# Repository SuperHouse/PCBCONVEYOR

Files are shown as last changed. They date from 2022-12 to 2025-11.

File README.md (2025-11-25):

PCB Conveyor Belt
=================

Copyright 2021 SuperHouse Automation Pty Ltd  www.superhouse.tv

THIS IS VERY PRELIMINARY! I'm adding this work-in-progress to GitHub
so that Seon can access it, but it's not in a ready state for
general consumption.
^^^^^^^^^^^^^^^^^^^^^^^^^^^^^^^^^^^^^^^^^^^^^^^^^^^^^^^^^^^^^^^

A conveyor belt for linking together PCB assembly machines, including
pick-and-place, reflow, optical inspection, etc.

The width of the belt is adjustable to suit different sizes of PCBs
and panels. This project includes the design for the mechanical
structure, a controller, and firmware for the controller.

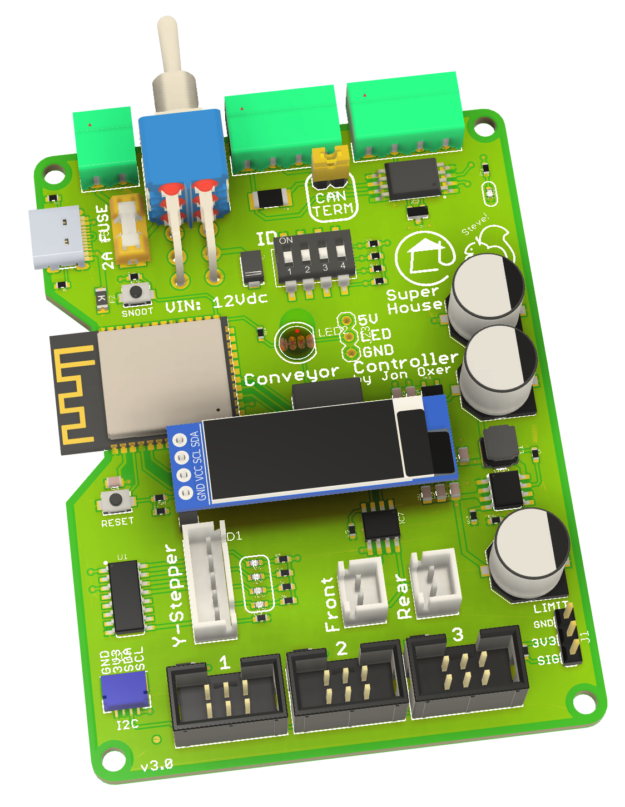
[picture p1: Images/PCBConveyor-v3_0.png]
PCBConveyor controller v3.0 PCB Controller


More information:

  http://www.superhouse.tv/pcbconveyor

INSTALLATION
------------
The "Hardware" directory contains the PCB design as an EAGLE project.
This can be imported into KiCAD, or opened natively using Fusion360.

CREDITS
-------
Designed by Jonathan Oxer jon@oxer.com.au

DISTRIBUTION
------------
The specific terms of distribution of this project are governed by the
license referenced below.

LICENSE
-------
Licensed under the TAPR Open Hardware License (www.tapr.org/OHL).
The "license" folder within this repository also contains a copy of
this license in plain text format.

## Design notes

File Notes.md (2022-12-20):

Design Notes
============

## Features

 * Speed control. Perhaps H-bridge motor drivers to allow reversing.
 * Width control. Needs a stepper driver. External module?
 * Ready-in / Ready-out connections.
 * Sensors at both ends to detect incoming / outgoing boards.
 * Ethernet to receive configuration commands.
 * Numeric keypad to set width / speed.
 * Display to show width setting.
 * Homing switch.
 * Calibration of homing switch offset.
 * Configure width using gcode commands.
 * Maybe configure speed using gcode too? Like spindle speed / direction.

I/O: Use MCP23017, and expose the extra pins on a spare header?

## General notes

Example conveyor:

https://www.alibaba.com/product-detail/KAYO-300-Automatic-PCB-Output-Connected_62495647850.html

Specs say that is 600-2200mm/min.

N20 motor 100RPM:

 * 12V = 3620mm/min
 * 4V = 1130mm/min
 * 3V = 780mm/min
 
Height from floor: SMEMA spec says 37" to 38" (940mm to 965mm)

## Software
The controller can be combined as a single device that provides the UI and also controls
the hardware, using custom firmware, OR it can be split so there's an I/O controller as
part of the chassis and a separate UI device.

The second approach as the advantage that the I/O controller can run GRBL:

 * Only enable the Y axis.
 * Use the spindle output to control the conveyor motor:
   * Spindle PWM speed control.
   * Spindle direction control.

With a separate I/O controller, it could be controlled by plugging in a USB cable from
a laptop and not having a UI controller at all.

https://github.com/gnea/grbl

However, how would it do ready-in/ready-out, and board detection? Custom firmware may
be better for those things.

### User Interface
https://www.bitsanddroids.com/creating-our-first-esp32-flight-display-graphics/

## Lighting
Should there be LED strips along the inside faces of the conveyor arms?

## Connections for controller

 * Ethernet
 * USB
 * 12V (PoE option)
 * Ready-in
 * Ready-out
 * Motor 1 out
 * Motor 2 out
 * Left-side sensor
 * Right-side sensor

## Controller
http://www.wireless-tag.com/portfolio/wt32-sc01/

### LCD driver
https://github.com/moononournation/Arduino_GFX

https://github.com/moononournation/Arduino_GFX/wiki/Dev-Device-Declaration

#include <Arduino_GFX_Library.h>
#define TFT_BL 23
Arduino_DataBus *bus = new Arduino_ESP32SPI(21 /* DC */, 15 /* CS */, 14 /* SCK */, 13 /* MOSI */, -1 /* MISO */);
Arduino_GFX *gfx = new Arduino_ST7796(bus, 22 /* RST */, 3 /* rotation */);

https://haswitchplate.github.io/openHASP-docs/0.6/devices/wt32-sc01/

https://www.alibaba.com/product-detail/WT32-SC01-ESP32-Dev-kitC-with_1600120762835.html

### Touch screen driver

https://stackoverflow.com/questions/58472138/find-ft6336-touch-screen-library-for-esp32

https://github.com/crystalfontz/CFAF240400C0-030SC/blob/master/CFAF240400C0030T/CFAF240400C0030SC.ino

https://github.com/strange-v/FT6X36

## Upstream / downstream connections

Needs a way to read from the adjacent device, and also to signal to
that device.

Open-collector input, with GND connection, a pullup, and a data in.

Dry-contact output. Perhaps a reed relay?

## Movement logic

### Incoming board

When there is no board ready to be sent, upstreams RO will not be
asserted.

When we're not ready for a board, our RI will not be asserted.

When upstream is ready to send a board, its RO will be asserted.

When we're ready to receive a board, our RI will be asserted.

When both RO and RI on upstream are asserted, start the belt.

## Board sensor

Sensor type: VL53L0X

VDD  Regulated 2.8 V output. Almost 150 mA is available to power
  external components. (If you want to bypass the internal regulator,
  you can instead use this pin as a 2.8 V input with VIN disconnected.)
 
VIN  This is the main 2.6 V to 5.5 V power supply connection. The SCL
  and SDA level shifters pull the I2C lines high to this level.
 
GND  The ground (0 V) connection for your power supply. Your I2C
  control source must also share a common ground with this board.
 
SDA  Level-shifted I2C data line: HIGH is VIN, LOW is 0 V
 
SCL  Level-shifted I2C clock line: HIGH is VIN, LOW is 0 V
 
XSHUT  This pin is an active-low shutdown input; the board pulls it up
  to VDD to enable the sensor by default. Driving this pin low puts
  the sensor into hardware standby. This input is not level-shifted. 

I2C address is 0x29 and can't be changed in hardware. The driver can
change it on startup. Use XSHUT to hold all others in shutdown while
that's being done.

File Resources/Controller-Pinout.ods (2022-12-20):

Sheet: Requirements
Count | Signal | Dir | Pin | Notes
1 | COPI | O | IO23
2 | CIPO | I | IO19
3 | SCK | O | IO18
4 | RFM69 CS | O | IO5
5 | SCL | O | IO22
6 | SDA | O | IO21
7 | RFM69 DIO0 | O | IO27
8 | Piezo | O | IO26
9 | Buttons | I | IO35 | Resistor Ladder
10 | Drive Motor PWM | O | IO16 | PWM
11 | Motor Relay A | O | IO17
12 | Motor Relay B | O | IO4
13 | Actuator Direction | O | IO25
14 | Encoder A | I | IO36
15 | Encoder B | I | IO39
16 | Limit Switches | I | IO34 | Resistor Ladder

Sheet: ESP32 Pinout
Pin | Input | Output | Notes | Touch | ADC | PWM | DAC | UART | SPI | I2C | Strap | HAB | Use
GPIO0 | Pulled up | OK | Outputs PWM signal at boot | T1 | ADC2_CH1 |  |  |  |  |  | Y |  | Boot Mode
GPIO2 | OK | OK | Connected to onboard LED | T2 | ADC2_CH2 | Y |  |  |  |  | Y |  | IN1
GPIO4 | OK | OK |  | T0 | ADC2_CH0 | Y |  |  |  |  | Y |  | IN2
GPIO5 | OK | OK | Outputs PWM signal at boot |  |  | Y |  |  | SS |  | Y | Y | IN3
GPIO12 | OK | OK | Boot fail if pulled high | T5 | ADC2_CH5 | Y |  |  |  |  | Y |  | IN4
GPIO13 | OK | OK |  | T4 | ADC2_CH4 | Y |  |  |  |  |  |  | LCD SDA
GPIO14 | OK | OK | Outputs PWM signal at boot | T6 | ADC2_CH6 | Y |  |  |  |  |  | Y | LCD SCL
GPIO15 | OK | OK | Outputs PWM signal at boot | T3 | ADC2_CH3 | Y |  |  |  |  | Y | Y | LCD CS
GPIO18 | OK | OK |  |  |  | Y |  |  | SCK |  |  |  | I2C SDA
GPIO19 | OK | OK |  |  |  | Y |  | CTS | CIPO |  |  |  | I2C SCL
GPIO21 | OK | OK |  |  |  | Y |  |  |  | SDA |  |  | LCD RS
GPIO22 | OK | OK |  |  |  | Y |  | RTS |  | SCL |  |  | LCD RST
GPIO23 | OK | OK |  |  |  | Y |  |  | COPI |  |  |  | LCD LED
GPIO25 | OK | OK |  |  | ADC2_CH8 | Y | DAC1 |  |  |  |  |  | MOTOR_1
GPIO26 | OK | OK |  |  | ADC2_CH9 | Y | DAC2 |  |  |  |  |  | MOTOR_2
GPIO27 | OK | OK |  | T7 | ADC2_CH7 | Y |  |  |  |  |  |  | ok
GPIO32 | OK | OK | Modify WROVER to use as output | T9 | ADC1_CH4 | Y |  |  |  |  |  |  | ok | https://www.esp32.com/viewtopic.php?t=2803
GPIO33 | OK | OK | Modify WROVER to use as output | T8 | ADC1_CH5 | Y |  |  |  |  |  |  | ok | https://www.esp32.com/viewtopic.php?t=2803
GPIO34 | OK | x | Input only. No pullup / pulldown. |  | ADC1_CH6 |  |  |  |  |  |  |  | ok
GPIO36 | OK | x | Input only. No pullup / pulldown. |  | ADC1_CH0 |  |  |  |  |  |  |  | ok | SENS_VP
GPIO39 | OK | x | Input only. No pullup / pulldown. |  | ADC1_CH3 |  |  |  |  |  |  |  | Limit sensor input | SENS_VN
 |  |  |  |  | ADC2 doesn't work when WiFi is in use

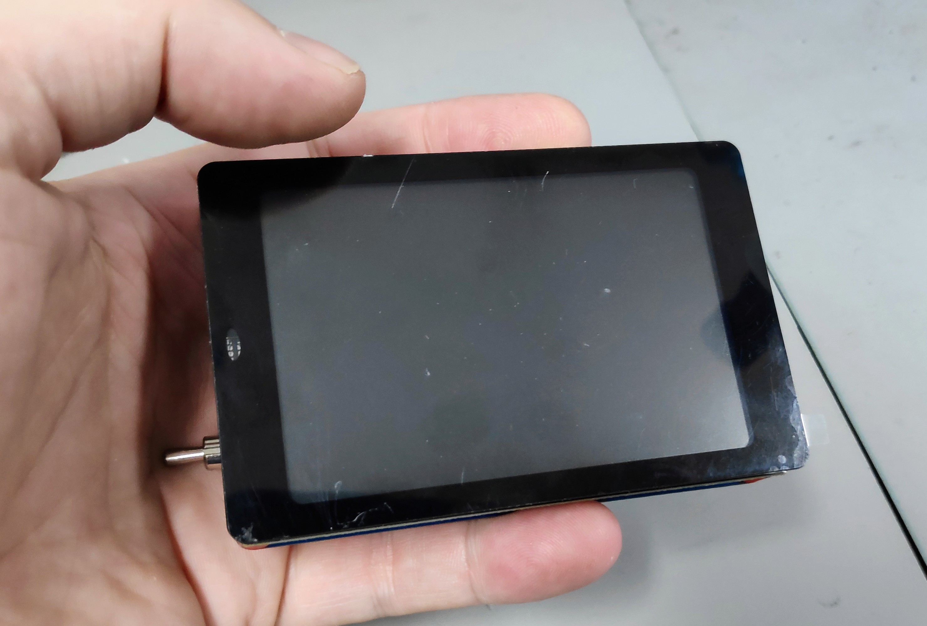
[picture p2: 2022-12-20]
Images/2022-03-01 10.30.43.jpg

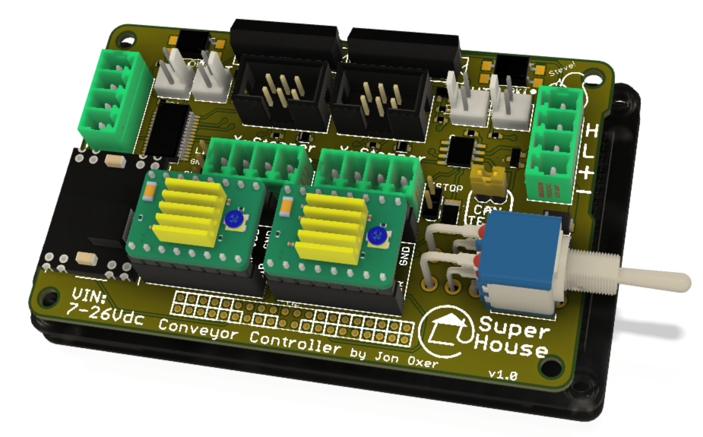
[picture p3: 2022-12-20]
Images/Screen Shot 2022-02-26 at 9.11.51 pm.png

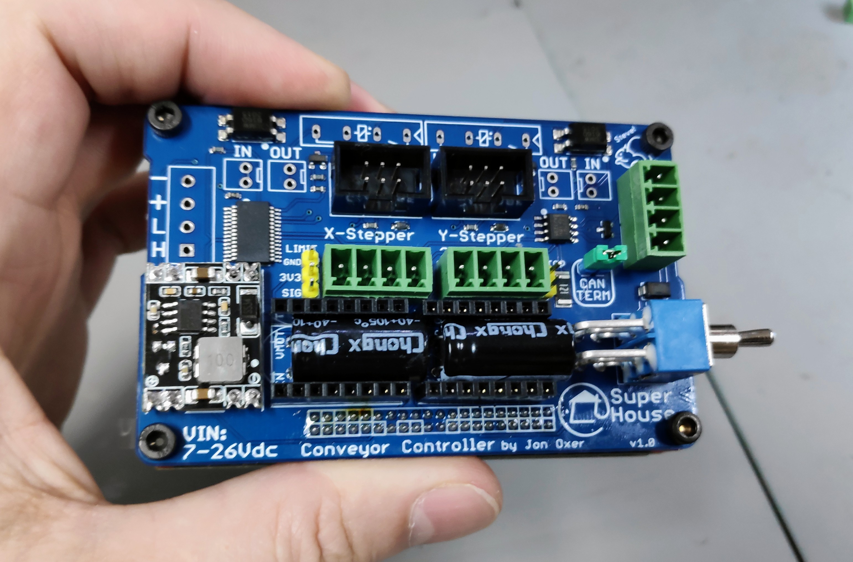
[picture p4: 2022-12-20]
Images/2022-03-01 10.30.50.jpg

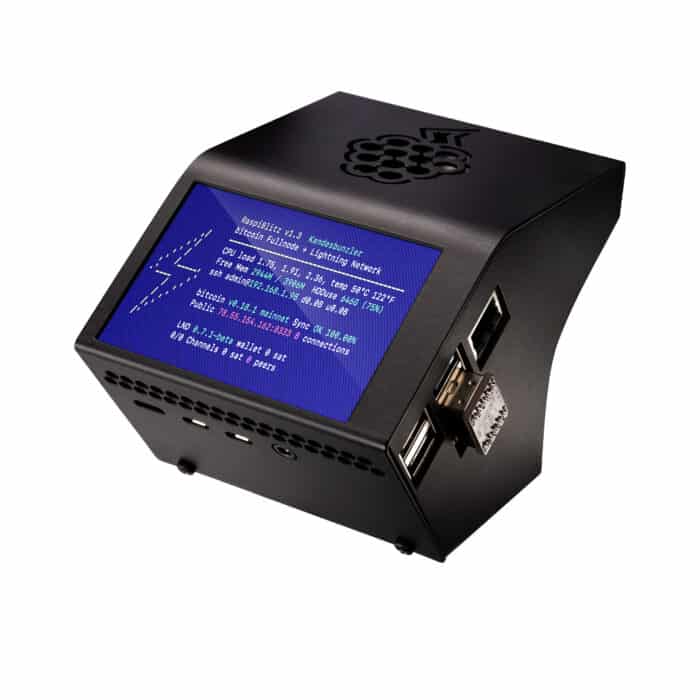
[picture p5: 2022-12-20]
Images/RaspiBlitz-Case.jpeg

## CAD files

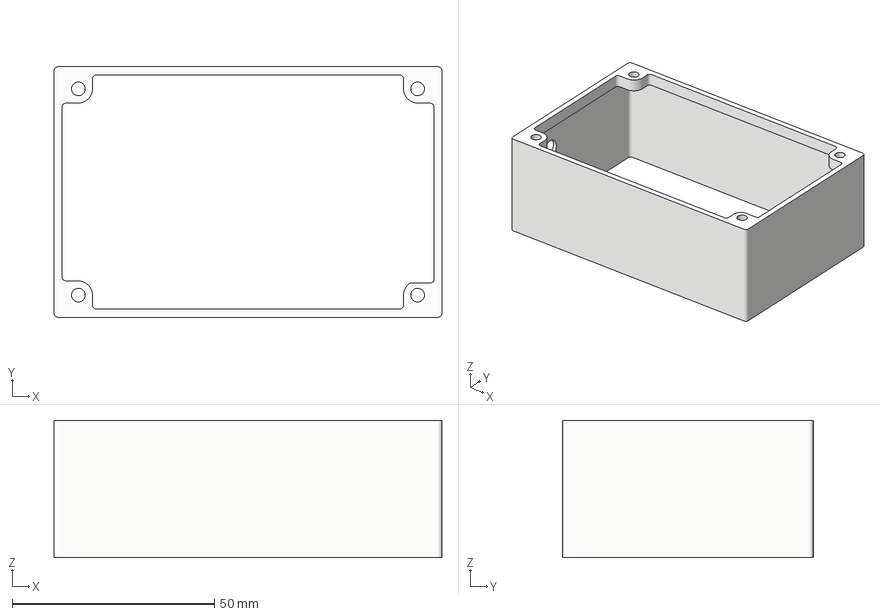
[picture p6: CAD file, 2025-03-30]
Mechanical/Conveyor Controller Mount.3mf
96.0 x 62.0 x 34.0 mm

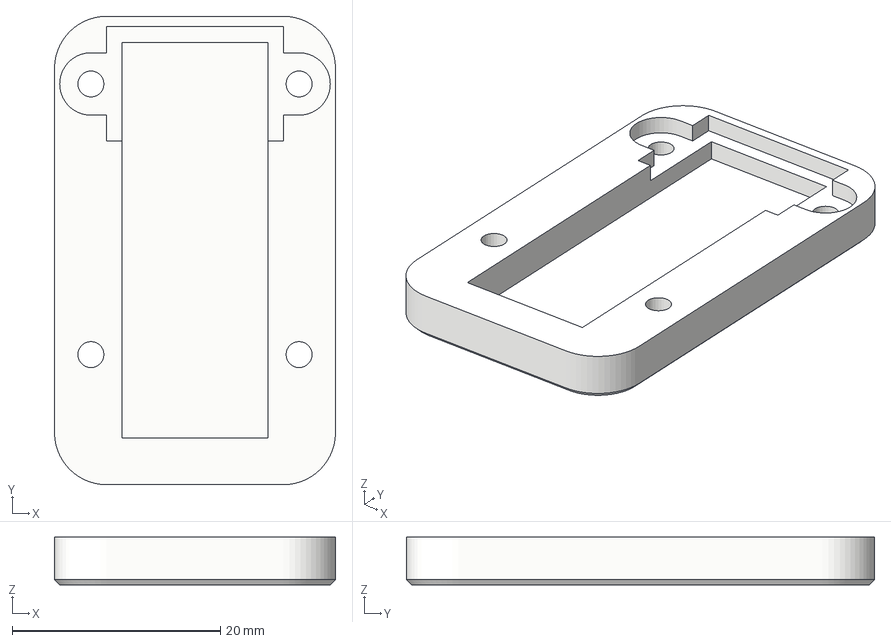
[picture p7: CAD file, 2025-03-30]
Mechanical/PCB Sensor Housing Base.3mf
27.0 x 45.0 x 4.60 mm

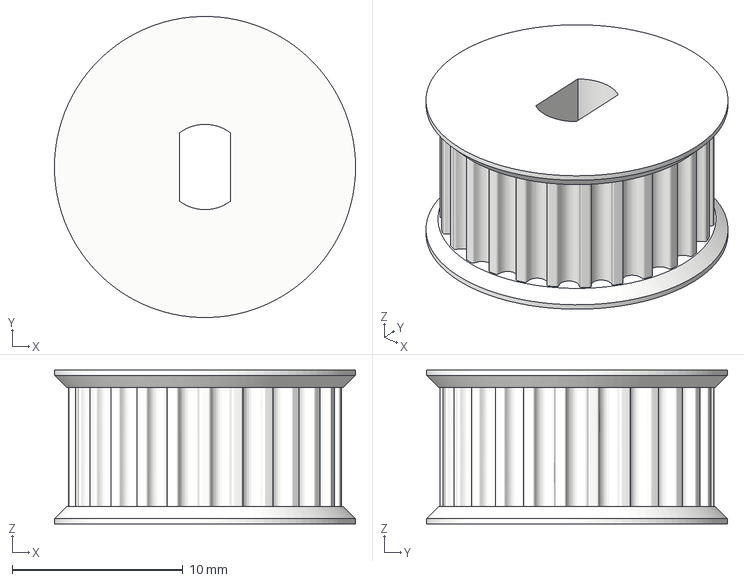
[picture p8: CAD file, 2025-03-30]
Mechanical/Belt Pulley GT2.3mf
17.6 x 17.6 x 9.00 mm

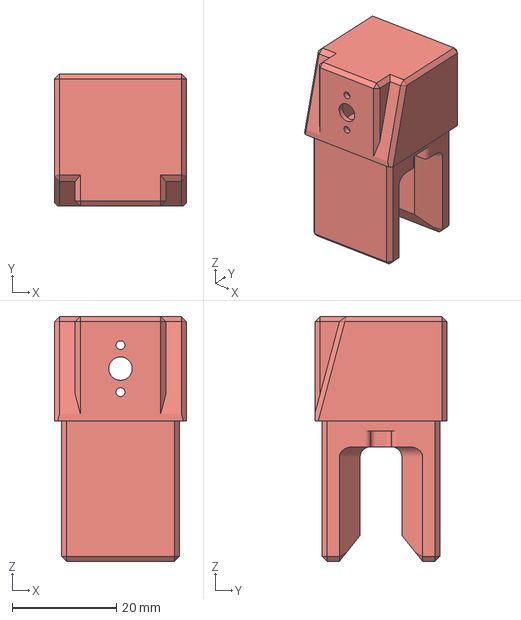
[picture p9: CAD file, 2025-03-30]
Mechanical/Conveyor Motor Mount.3mf
25.4 x 25.4 x 47.0 mm

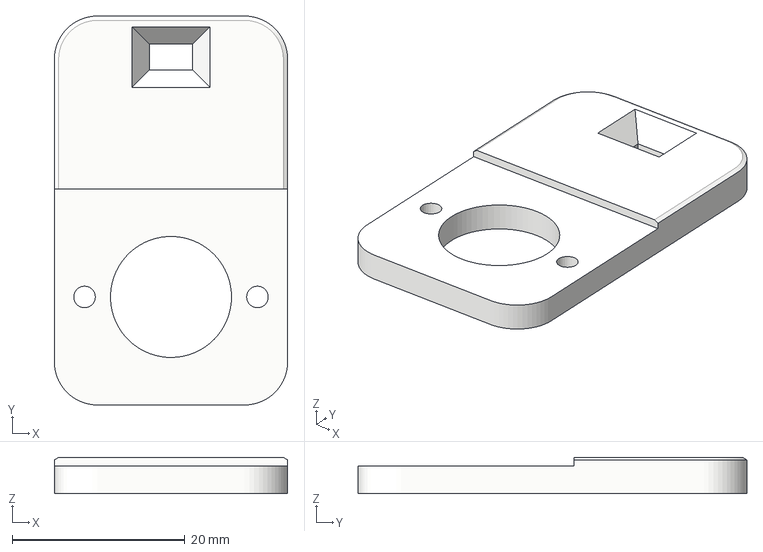
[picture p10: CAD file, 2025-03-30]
Mechanical/PCB Sensor Housing Cover.3mf
27.0 x 45.0 x 4.20 mm

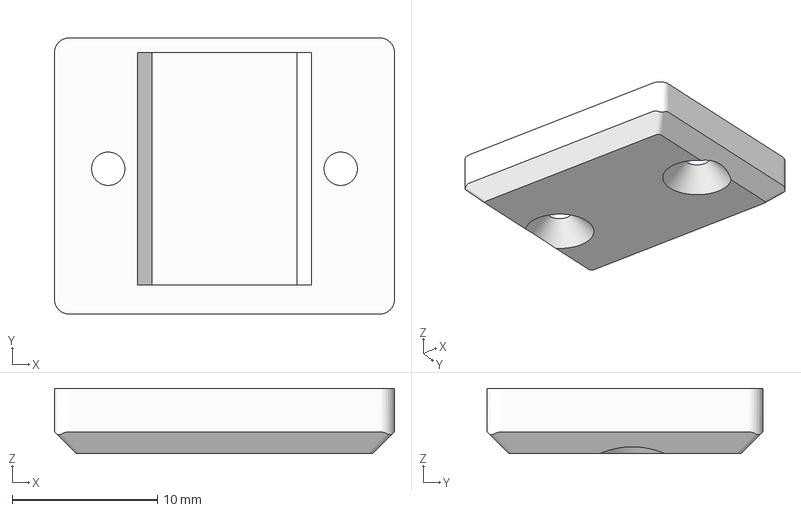
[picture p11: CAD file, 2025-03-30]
Mechanical/Conveyor Motor Cover.3mf
23.4 x 19.0 x 4.50 mm

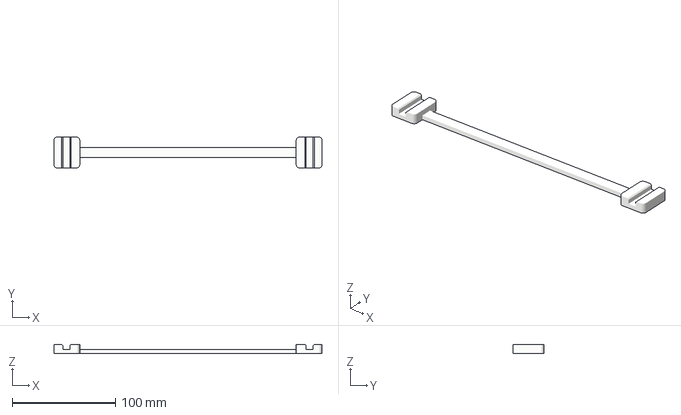
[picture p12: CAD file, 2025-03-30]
Mechanical/Linear Rail Spacer.3mf
260.0 x 30.0 x 8.80 mm

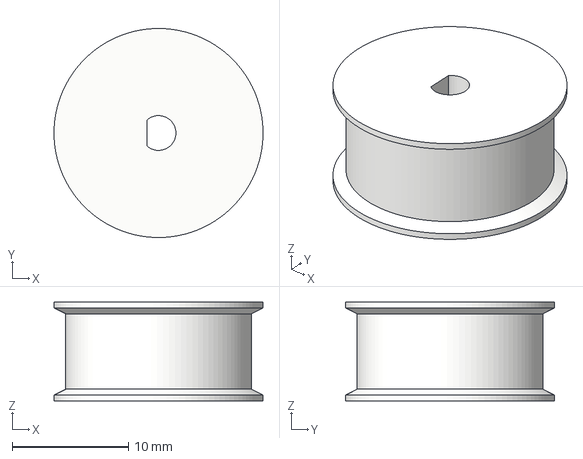
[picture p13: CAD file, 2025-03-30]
Mechanical/X Axis Belt Pulley.3mf
18.0 x 18.0 x 8.50 mm

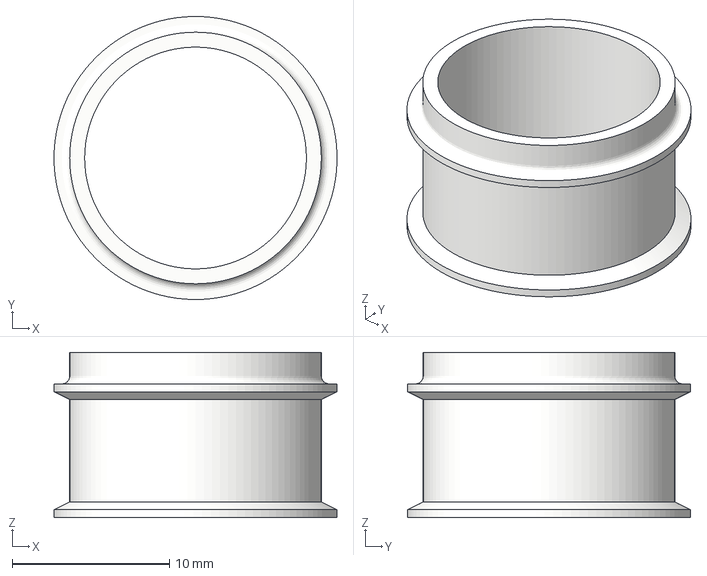
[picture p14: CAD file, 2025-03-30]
Mechanical/X Axis Belt Idler.3mf
18.0 x 18.0 x 10.5 mm

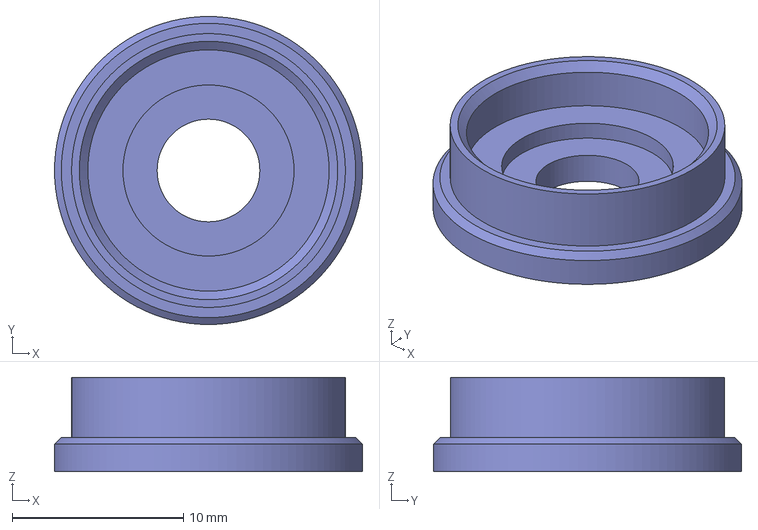
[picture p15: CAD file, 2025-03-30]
Mechanical/Y Axis Belt Idler GT2 16mm.3mf
18.0 x 18.0 x 5.50 mm

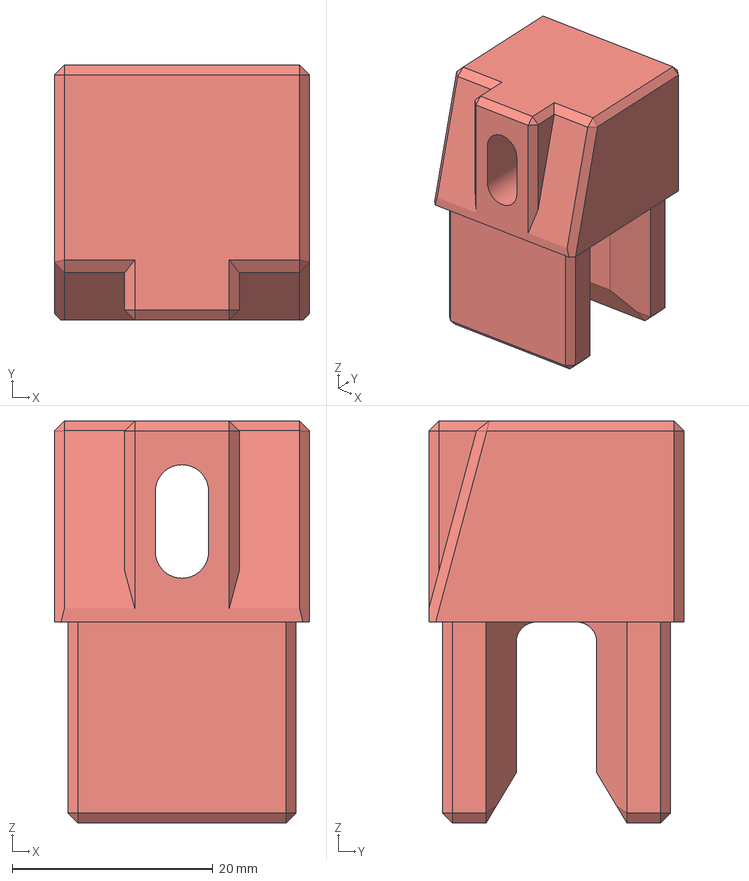
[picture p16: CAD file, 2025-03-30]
Mechanical/Conveyor Idler Mount.3mf
25.4 x 25.4 x 40.0 mm

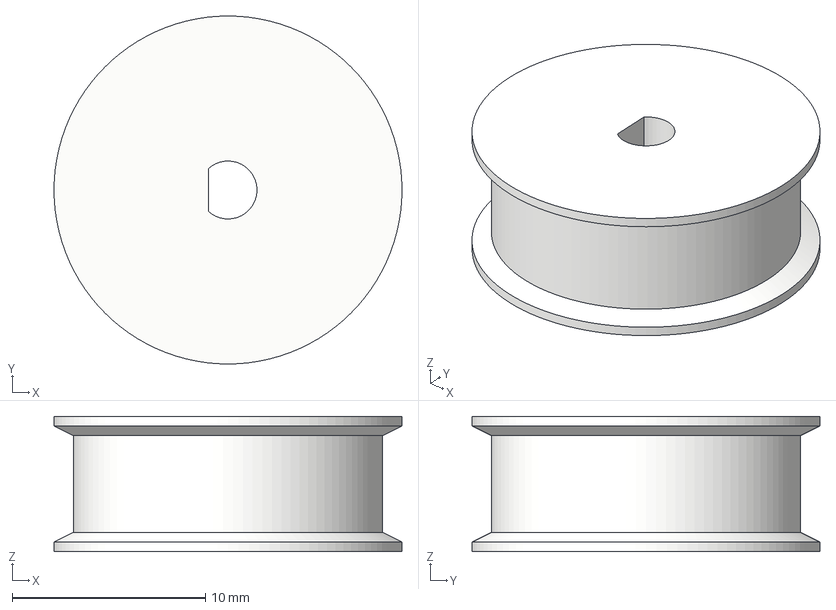
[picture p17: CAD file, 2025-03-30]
Mechanical/Belt Pulley Smooth.3mf
18.0 x 18.0 x 7.00 mm

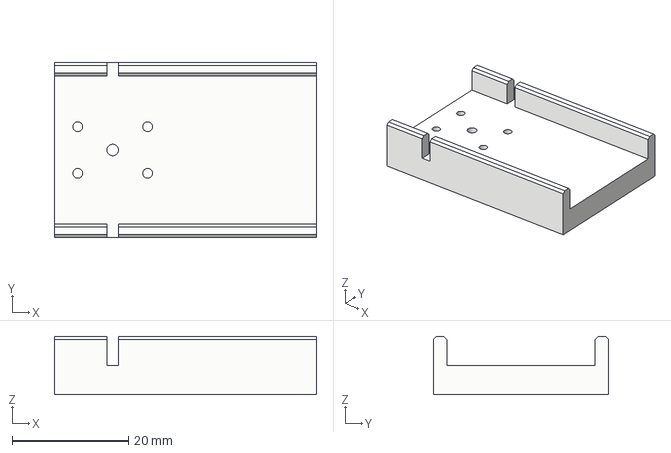
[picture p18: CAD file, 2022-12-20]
Mechanical/MGN7 Carriage Hole Template.3mf
45.0 x 30.0 x 10.0 mm

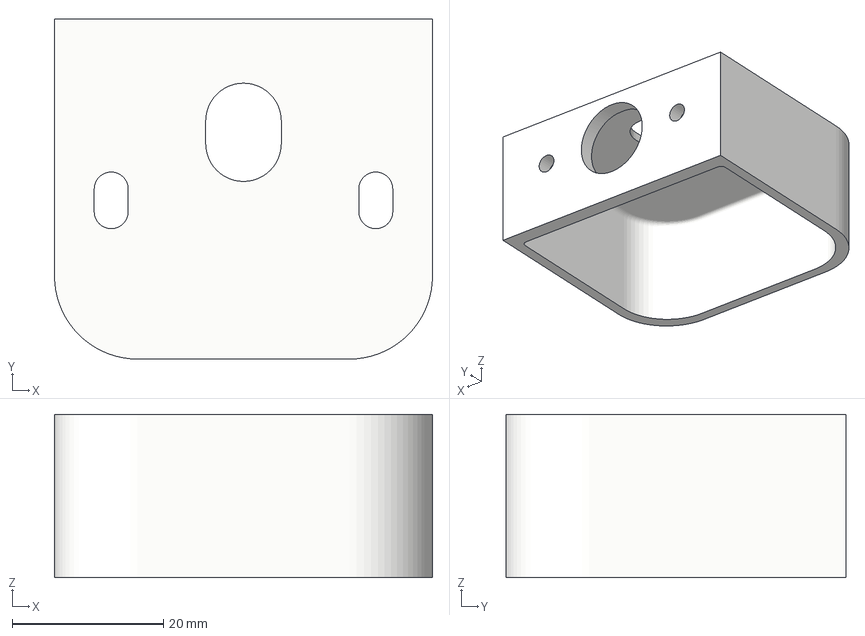
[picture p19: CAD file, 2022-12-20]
Mechanical/Stepper Motor Mount v3.3mf
50.0 x 45.0 x 21.6 mm

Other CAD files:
Mechanical/Belt Pulley Conveyor v3.3mf
Mechanical/Belt Idler Conveyor v6.3mf
Mechanical/Front Rail Hole Drilling Template.3mf
Mechanical/GT2 Timing Belt Clamp.3mf
Mechanical/16mm Idler.3mf
Mechanical/2-Way Right Angle.3mf
Mechanical/5mm Nut Spacer.3mf
Mechanical/Conveyor Idler Mount v7.3mf
Mechanical/Conveyor Motor Cover v2.3mf
Mechanical/Conveyor Motor Mount v3.3mf
Mechanical/Front Rail Spacer Block.3mf
Mechanical/GT2 Timing Belt Clamp Cover.3mf
Mechanical/Limit Switch Cover.3mf
Mechanical/Limit Switch Mount.3mf
Mechanical/PCB Holder PCBCONVEYOR.3mf
Mechanical/Sensor Probe.3mf
Mechanical/Y Axis GT2 Pulley.3mf
Mechanical/Y Axis Idler Clevis.3mf

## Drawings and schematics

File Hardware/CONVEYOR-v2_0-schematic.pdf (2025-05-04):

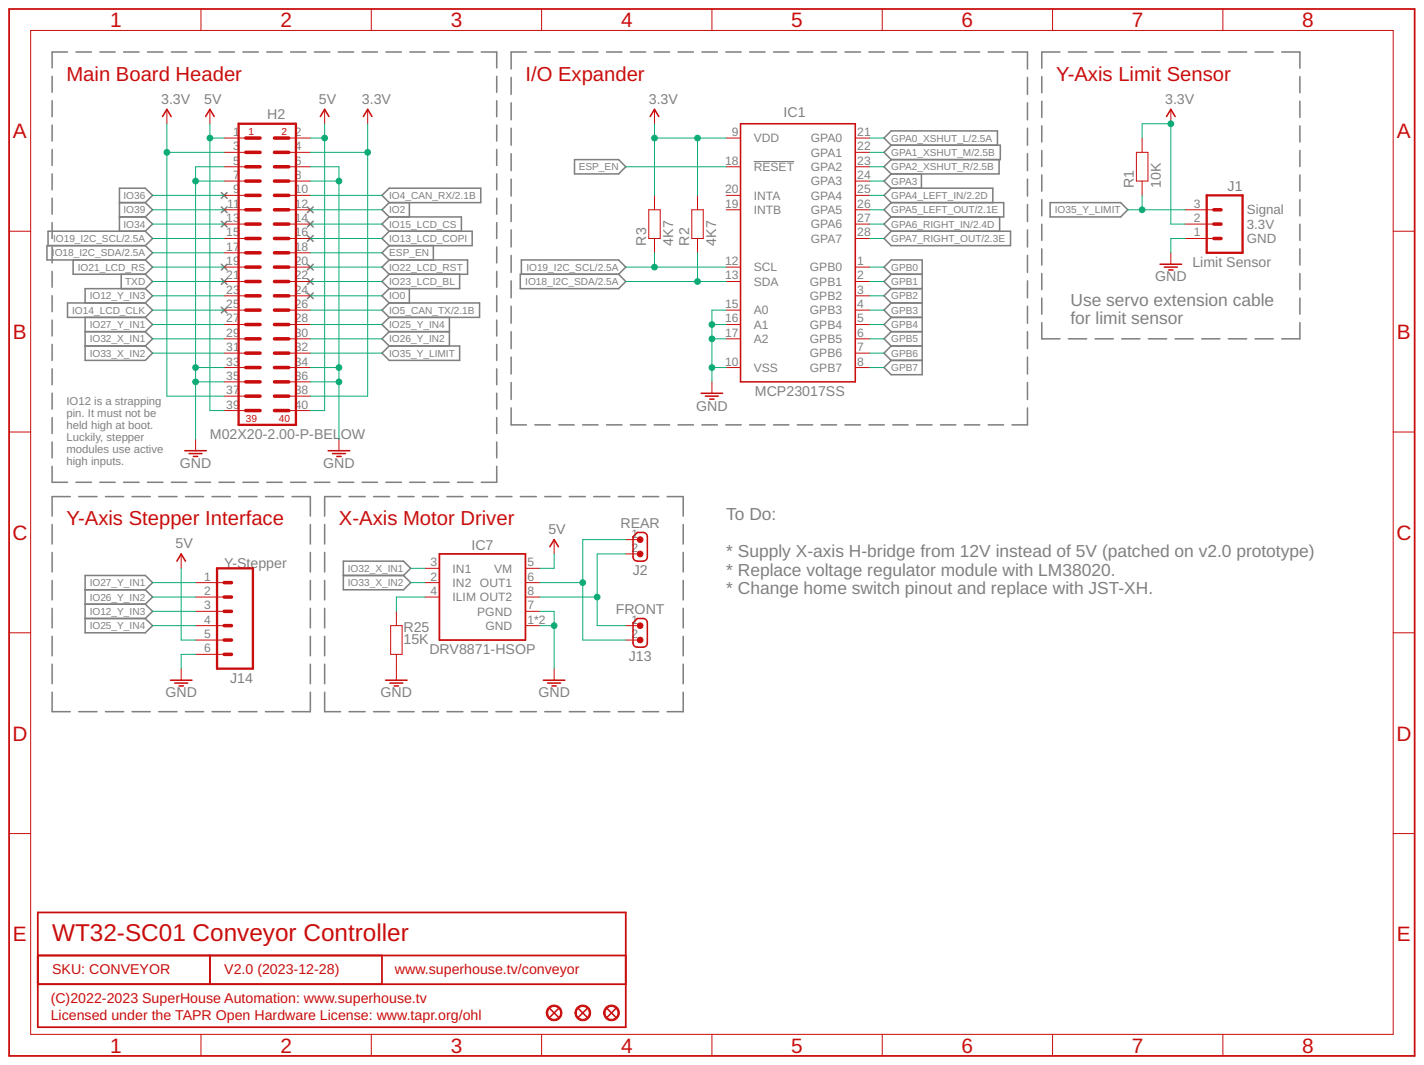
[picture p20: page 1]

Use servo extension cable
for limit sensor

16 | 5
17 | 6
10 | 7

IO12 is a strapping
pin. It must not be
held high at boot. Luckily, stepper modules use active

SKU: CONVEYOR
(C)2022-2023 SuperHouse Automation: www.superhouse.tv Licensed under the TAPR Open Hardware License: www.tapr.org/ohl

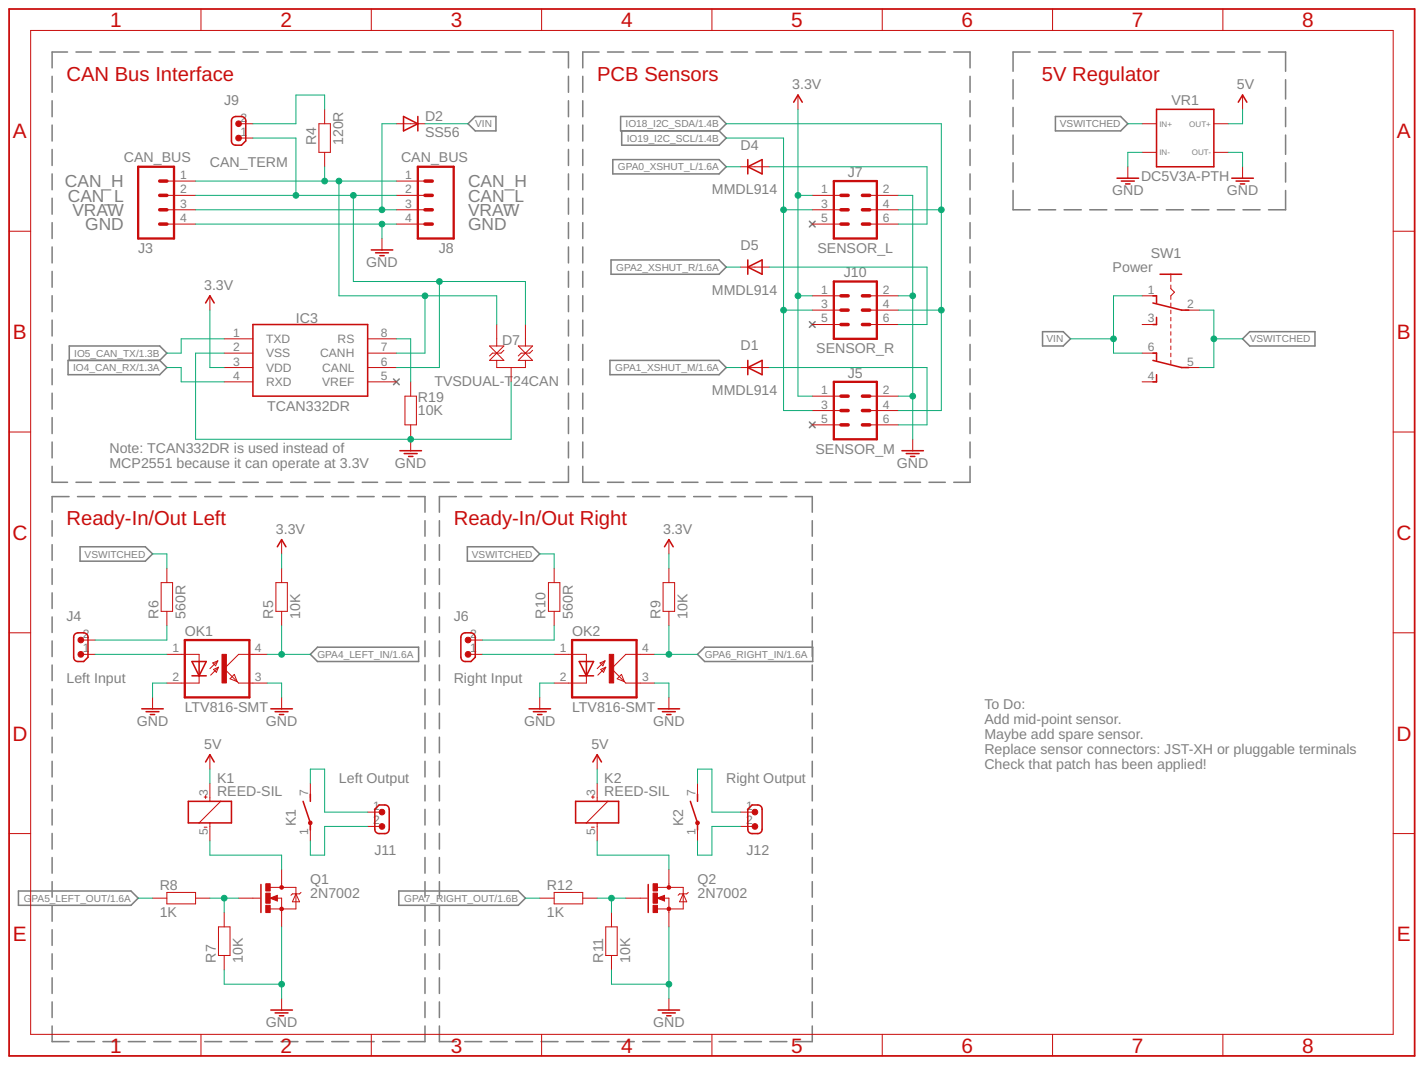
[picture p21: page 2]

Note: TCAN332DR is used instead of
MCP2551 because it can operate at 3.3V

To Do: Add mid-point sensor. Maybe add spare sensor. Replace sensor connectors: JST-XH or pluggable terminals Check that patch has been applied!

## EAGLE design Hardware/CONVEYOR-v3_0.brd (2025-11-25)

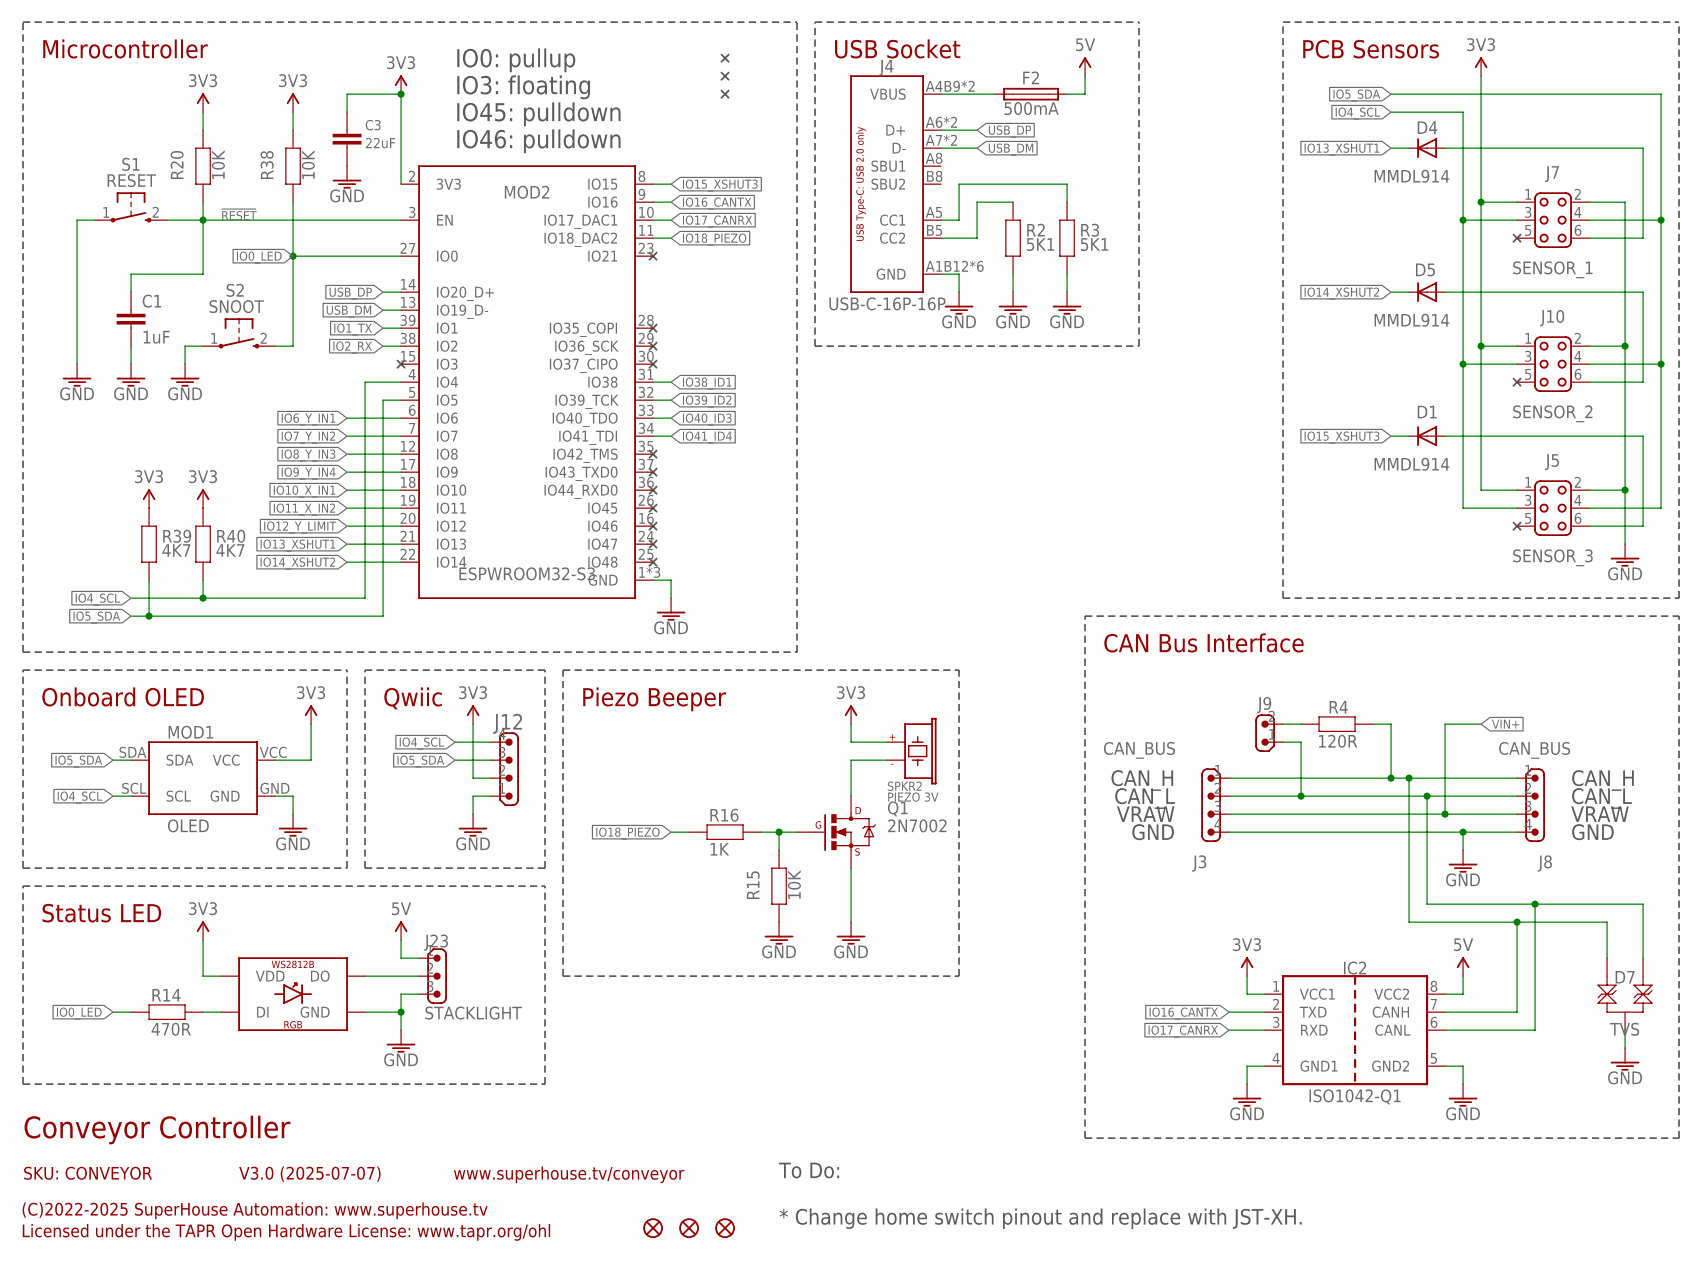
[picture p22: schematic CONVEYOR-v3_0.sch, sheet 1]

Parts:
C1: 1uF; C0603
C3: 22uF; C0805
D1, D4, D5: MMDL914; SOD-123
D7: TVS; SOT23-3
F2: 500mA; 1206
IC2: ISO1042-Q1; SO08-W
J3, J8: CAN_BUS; SCREWTERMINAL-3.81MM-PLUGGABLE-HOR-4
J4: USB-C-16P-16P; USB-C-16P
J5: SENSOR_3; 2X3-2.54-SHROUDED
J7: SENSOR_1; 2X3-2.54-SHROUDED
J9: M02-PIN-JUMP-Y; 1X02-P-JUMP-Y
J10: SENSOR_2; 2X3-2.54-SHROUDED
J12: M04-SM4B-SH; JST-SM4B-SH
J23: STACKLIGHT; 1X03
LED2: WS2812B-PTH5MM; 5MM4PIN
MOD1: OLED; OLED-128X32-0.91-HEADER
MOD2: ESPWROOM32-S3
Q1: 2N7002; SOT23-3
R2, R3: 5K1; R0603
R4: 120R; R2010
R14: 470R; R0603
R15, R20, R38: 10K; R0603
R16: 1K; R0603
R39, R40: 4K7; R0603
S1: RESET; TACTILE_SMT_3X4X2
S2: SNOOT; TACTILE_SMT_3X4X2
SPKR2: PIEZO 3V; PIEZO-9.6X9.6-SMT
U$4, U$5, U$6: FIDUCIAL1X2.5; FIDUCIAL-1X2.5

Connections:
3.3V: C3.1, IC2.1 (VCC1), J5.1, J7.1, J10.1, J12.2, LED2.2 (VDD), MOD1.VCC, MOD2.2 (3V3), R20.1, R38.1, R39.1, R40.1, SPKR2.1 (+); also elsewhere on the board
5V: F2.2, IC2.8 (VCC2), J23.1; also elsewhere on the board
!RESET: C1.1, MOD2.3 (EN), R20.2, S1.2 (S)
CAN_H1: D7.2, IC2.7 (CANH), J3.1, J8.1, R4.2
CAN_L1: D7.1, IC2.6 (CANL), J3.2, J8.2, J9.1
GND: C1.2, C3.2, D7.3, IC2.4 (GND1), IC2.5 (GND2), J3.4, J4.A1B12 (GND), J4.A12B1 (GND), J4.FIX1 (GND), J4.FIX2 (GND), J4.FIX3 (GND), J4.FIX4 (GND), J5.2, J7.2, J8.4, J10.2, J12.1, J23.3, LED2.3 (GND), MOD1.GND, MOD2.1 (GND), MOD2.40 (GND), MOD2.41 (GND), Q1.2 (S), R2.2, R3.2, R15.2, S1.1, S2.1; also elsewhere on the board
IO0_LED: MOD2.27 (IO0), R14.1, R38.2, S2.2 (S)
IO1_TX: MOD2.39 (IO1)
IO2_RX: MOD2.38 (IO2)
IO4_SCL: J5.3, J7.3, J10.3, J12.4, MOD1.SCL, MOD2.4 (IO4), R40.2
IO5_SDA: J5.4, J7.4, J10.4, J12.3, MOD1.SDA, MOD2.5 (IO5), R39.2
IO6_Y_IN1: MOD2.6 (IO6); also elsewhere on the board
IO7_Y_IN2: MOD2.7 (IO7); also elsewhere on the board
IO8_Y_IN3: MOD2.12 (IO8); also elsewhere on the board
IO9_Y_IN4: MOD2.17 (IO9); also elsewhere on the board
IO10_X_IN1: MOD2.18 (IO10); also elsewhere on the board
IO11_X_IN2: MOD2.19 (IO11); also elsewhere on the board
IO12_Y_LIMIT: MOD2.20 (IO12); also elsewhere on the board
IO13_XSHUT1: D4.1 (C), MOD2.21 (IO13)
IO14_XSHUT2: D5.1 (C), MOD2.22 (IO14)
IO15_XSHUT3: D1.1 (C), MOD2.8 (IO15)
IO16_CANTX: IC2.2 (TXD), MOD2.9 (IO16)
IO17_CANRX: IC2.3 (RXD), MOD2.10 (IO17_DAC1)
IO18_PIEZO: MOD2.11 (IO18_DAC2), R16.1
IO38_ID1: MOD2.31 (IO38); also elsewhere on the board
IO39_ID2: MOD2.32 (IO39_TCK); also elsewhere on the board
IO40_ID3: MOD2.33 (IO40_TDO); also elsewhere on the board
IO41_ID4: MOD2.34 (IO41_TDI); also elsewhere on the board
IO46: MOD2.16 (IO46)
unnamed: J9.2, R4.1
unnamed: LED2.4 (DI), R14.2
unnamed: D1.2 (A), J5.6
unnamed: J4.B5 (CC2), R2.1
unnamed: J4.A5 (CC1), R3.1
unnamed: F2.1, J4.A4B9 (VBUS), J4.A9B4 (VBUS)
unnamed: J23.2, LED2.1 (DO)
unnamed: D5.2 (A), J10.6
unnamed: Q1.1 (G), R15.1, R16.2
unnamed: Q1.3 (D), SPKR2.2 (-)
unnamed: D4.2 (A), J7.6
USB_DM: J4.A7 (D-), J4.B7 (D-), MOD2.13 (IO19_D-)
USB_DP: J4.A6 (D+), J4.B6 (D+), MOD2.14 (IO20_D+)
VIN+: J3.3, J8.3; also elsewhere on the board

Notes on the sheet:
Conveyor Controller
SKU: CONVEYOR
(C)2022-2025 SuperHouse Automation: www.superhouse.tv
Licensed under the TAPR Open Hardware License: www.tapr.org/ohl
www.superhouse.tv/conveyor
V3.0 (2025-07-07)
To Do: * Change home switch pinout and replace with JST-XH.
Piezo Beeper
Microcontroller
Qwiic
IO0: pullup IO3: floating IO45: pulldown IO46: pulldown
Status LED
PCB Sensors
Onboard OLED
USB Socket
CAN Bus Interface
CAN_H
CAN_L
GND
VRAW

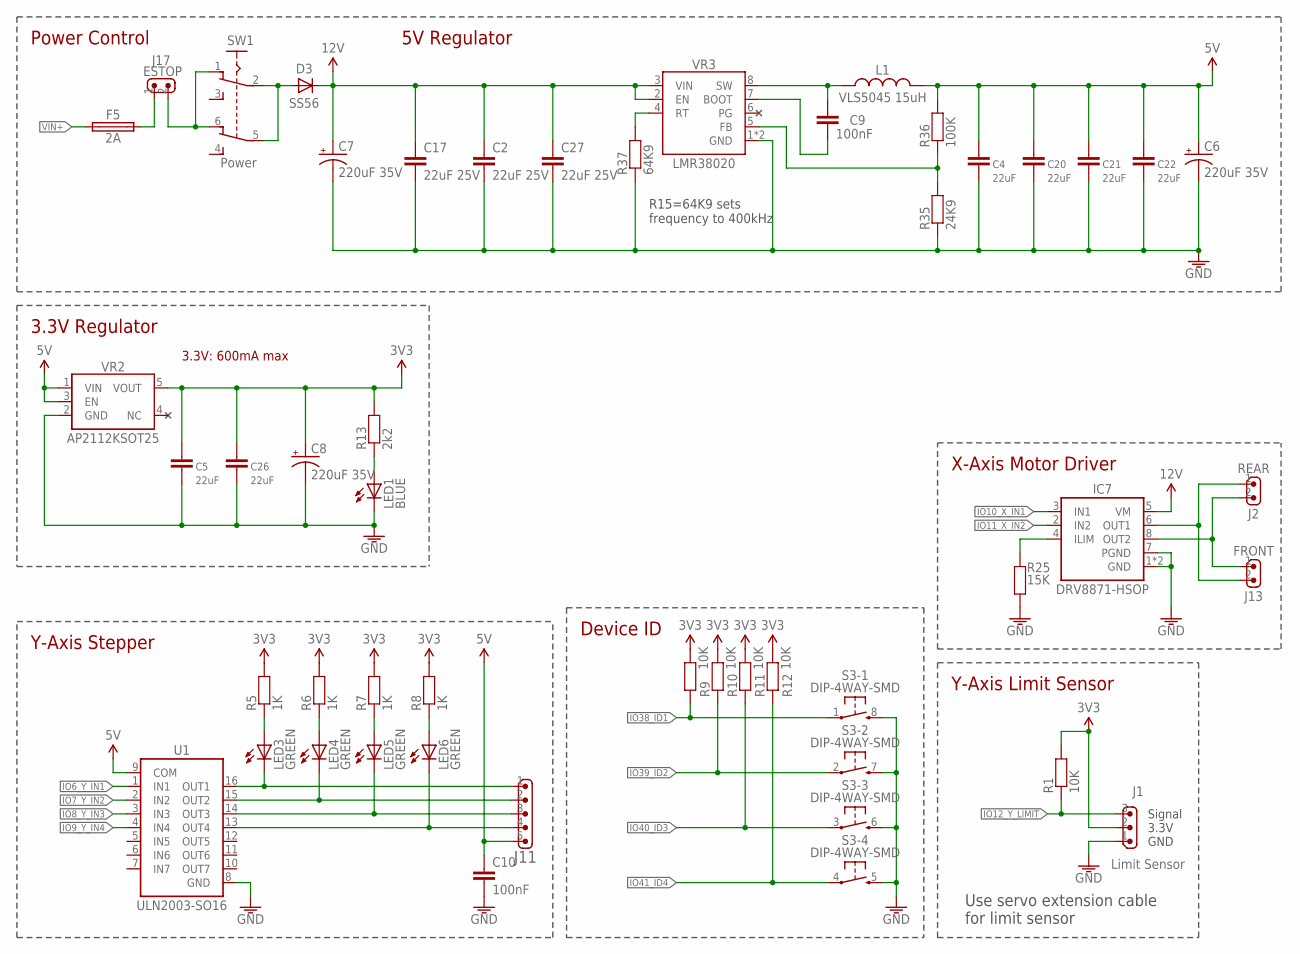
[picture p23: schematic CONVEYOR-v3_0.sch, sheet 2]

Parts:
C2, C17, C27: 22uF 25V; C0805
C4, C5, C20, C21, C22, C26: 22uF; C0805
C6, C7, C8: 220uF 35V; PANASONIC_G
C9, C10: 100nF; C0603
D3: SS56; SMA-DIODE
F5: 2A; OMNIBLOK
IC7: DRV8871-HSOP; SOIC8T
J1: Limit Sensor; 1X03-P
J2: REAR; JST-B2B-XH-A
J11: M05-B5B-XH; JST-B5B-XH-A
J13: FRONT; JST-B2B-XH-A
J17: ESTOP; SCREWTERMINAL-3.81MM-PLUGGABLE-HOR-2
L1: VLS5045 15uH; INDUCTOR-5045
LED1: BLUE; LED-0603
LED3, LED4, LED5, LED6: GREEN; LED-0603
R1, R9, R10, R11, R12: 10K; R0603
R5, R6, R7, R8: 1K; R0603
R13: 2k2; R0603
R25: 15K; R0603
R35: 24K9; R0603
R36: 100K; R0603
R37: 64K9; R0603
S3: DIP-4WAY-SMD; DIP-8-SMD
SW1: Power; 7201SD9AV2BE
U1: ULN2003-SO16; SO16
VR2: AP2112KSOT25; SOT23-5
VR3: LMR38020; HSOIC8

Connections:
3.3V: C5.1, C8.+, C26.1, J1.2, R1.2, R5.2, R6.2, R7.2, R8.2, R9.2, R10.2, R11.2, R12.2, R13.2, VR2.5 (VOUT); also elsewhere on the board
5V: C4.1, C6.+, C10.1, C20.1, C21.1, C22.1, J11.5, L1.2, R36.2, U1.9 (COM), VR2.1 (VIN), VR2.3 (EN); also elsewhere on the board
12V: C2.1, C7.+, C17.1, C27.1, D3.C, IC7.5 (VM), VR3.2 (EN), VR3.3 (VIN)
GND: C2.2, C4.2, C5.2, C6.-, C7.-, C8.-, C10.2, C17.2, C20.2, C21.2, C22.2, C26.2, C27.2, IC7.1 (GND), IC7.7 (PGND), IC7.TGND (GND), J1.1, LED1.C, R25.1, R35.1, R37.1, S3.5 (S), S3.6 (S), S3.7 (S), S3.8 (S), U1.8 (GND), VR2.2 (GND), VR3.1 (GND), VR3.TGND (GND); also elsewhere on the board
IO6_Y_IN1: U1.1 (IN1); also elsewhere on the board
IO7_Y_IN2: U1.2 (IN2); also elsewhere on the board
IO8_Y_IN3: U1.3 (IN3); also elsewhere on the board
IO9_Y_IN4: U1.4 (IN4); also elsewhere on the board
IO10_X_IN1: IC7.3 (IN1); also elsewhere on the board
IO11_X_IN2: IC7.2 (IN2); also elsewhere on the board
IO12_Y_LIMIT: J1.3, R1.1; also elsewhere on the board
IO38_ID1: R9.1, S3.1; also elsewhere on the board
IO39_ID2: R10.1, S3.2; also elsewhere on the board
IO40_ID3: R11.1, S3.3; also elsewhere on the board
IO41_ID4: R12.1, S3.4; also elsewhere on the board
unnamed: J17.2, SW1.1, SW1.6
unnamed: IC7.4 (ILIM), R25.2
unnamed: F5.2, J17.1
unnamed: D3.A, SW1.2, SW1.5
unnamed: LED3.A, R5.1
unnamed: J11.1, LED3.C, U1.16 (OUT1)
unnamed: LED4.A, R6.1
unnamed: LED5.A, R7.1
unnamed: LED6.A, R8.1
unnamed: J11.2, LED4.C, U1.15 (OUT2)
unnamed: J11.3, LED5.C, U1.14 (OUT3)
unnamed: J11.4, LED6.C, U1.13 (OUT4)
unnamed: IC7.6 (OUT1), J2.1, J13.2
unnamed: IC7.8 (OUT2), J2.2, J13.1
unnamed: LED1.A, R13.1
unnamed: C9.1, L1.1, VR3.8 (SW)
unnamed: R37.2, VR3.4 (RT)
unnamed: R35.2, R36.1, VR3.5 (FB)
unnamed: C9.2, VR3.7 (BOOT)
PG: VR3.6 (PG)
VIN+: F5.1; also elsewhere on the board

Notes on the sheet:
3.3V: 600mA max
5V Regulator
3.3V Regulator
R15=64K9 sets frequency to 400kHz
Power Control
Y-Axis Stepper
Device ID
3.3V
Signal
GND
Use servo extension cable for limit sensor
Y-Axis Limit Sensor
X-Axis Motor Driver

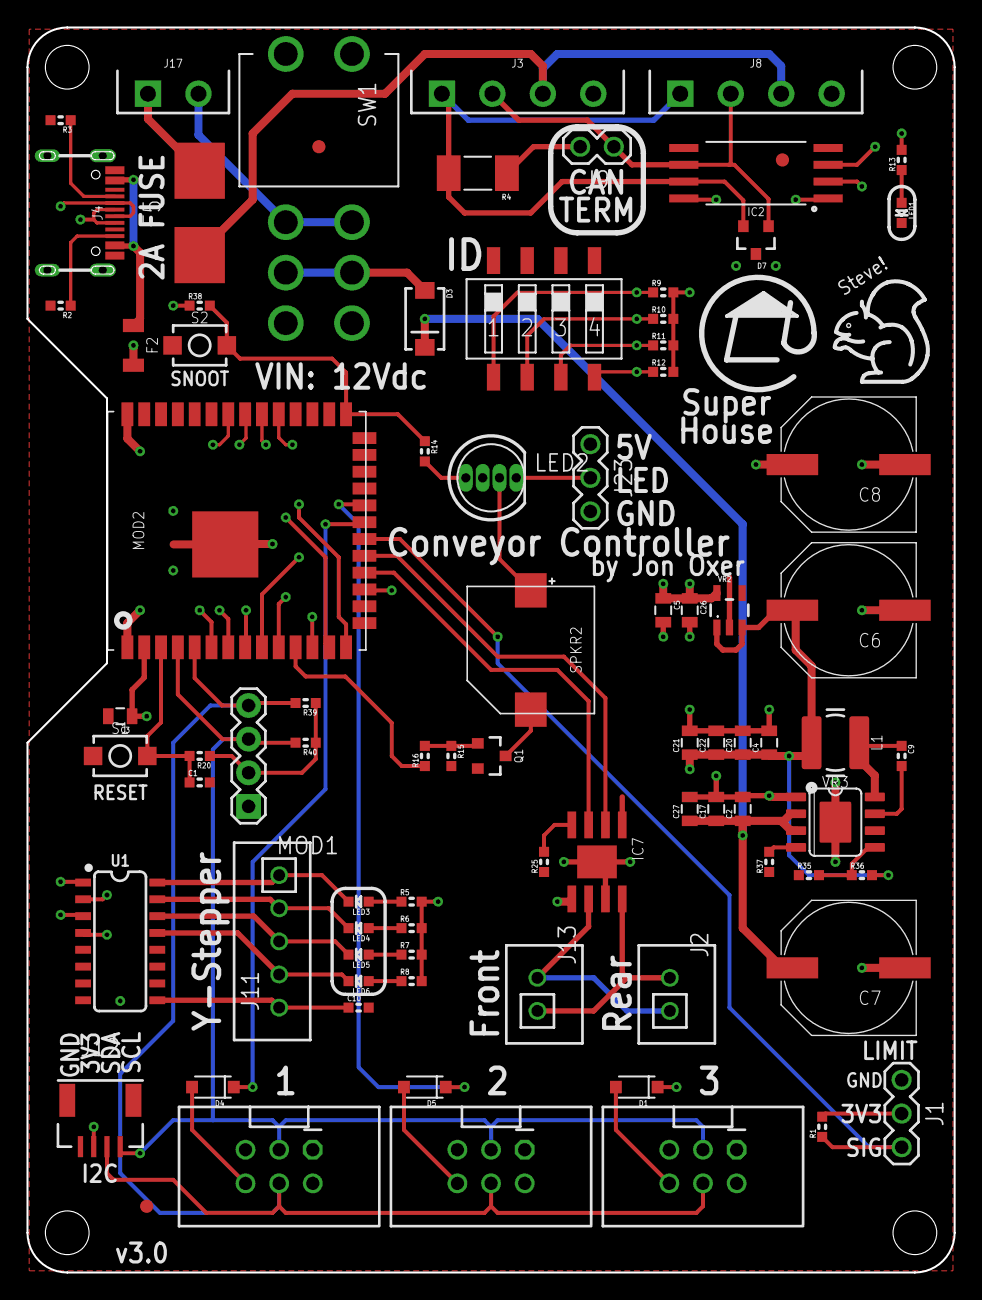
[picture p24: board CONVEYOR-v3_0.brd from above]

Board: 4 copper layers, 70.0 x 94.0 mm, 84 parts (0 on the bottom side), 60 nets.

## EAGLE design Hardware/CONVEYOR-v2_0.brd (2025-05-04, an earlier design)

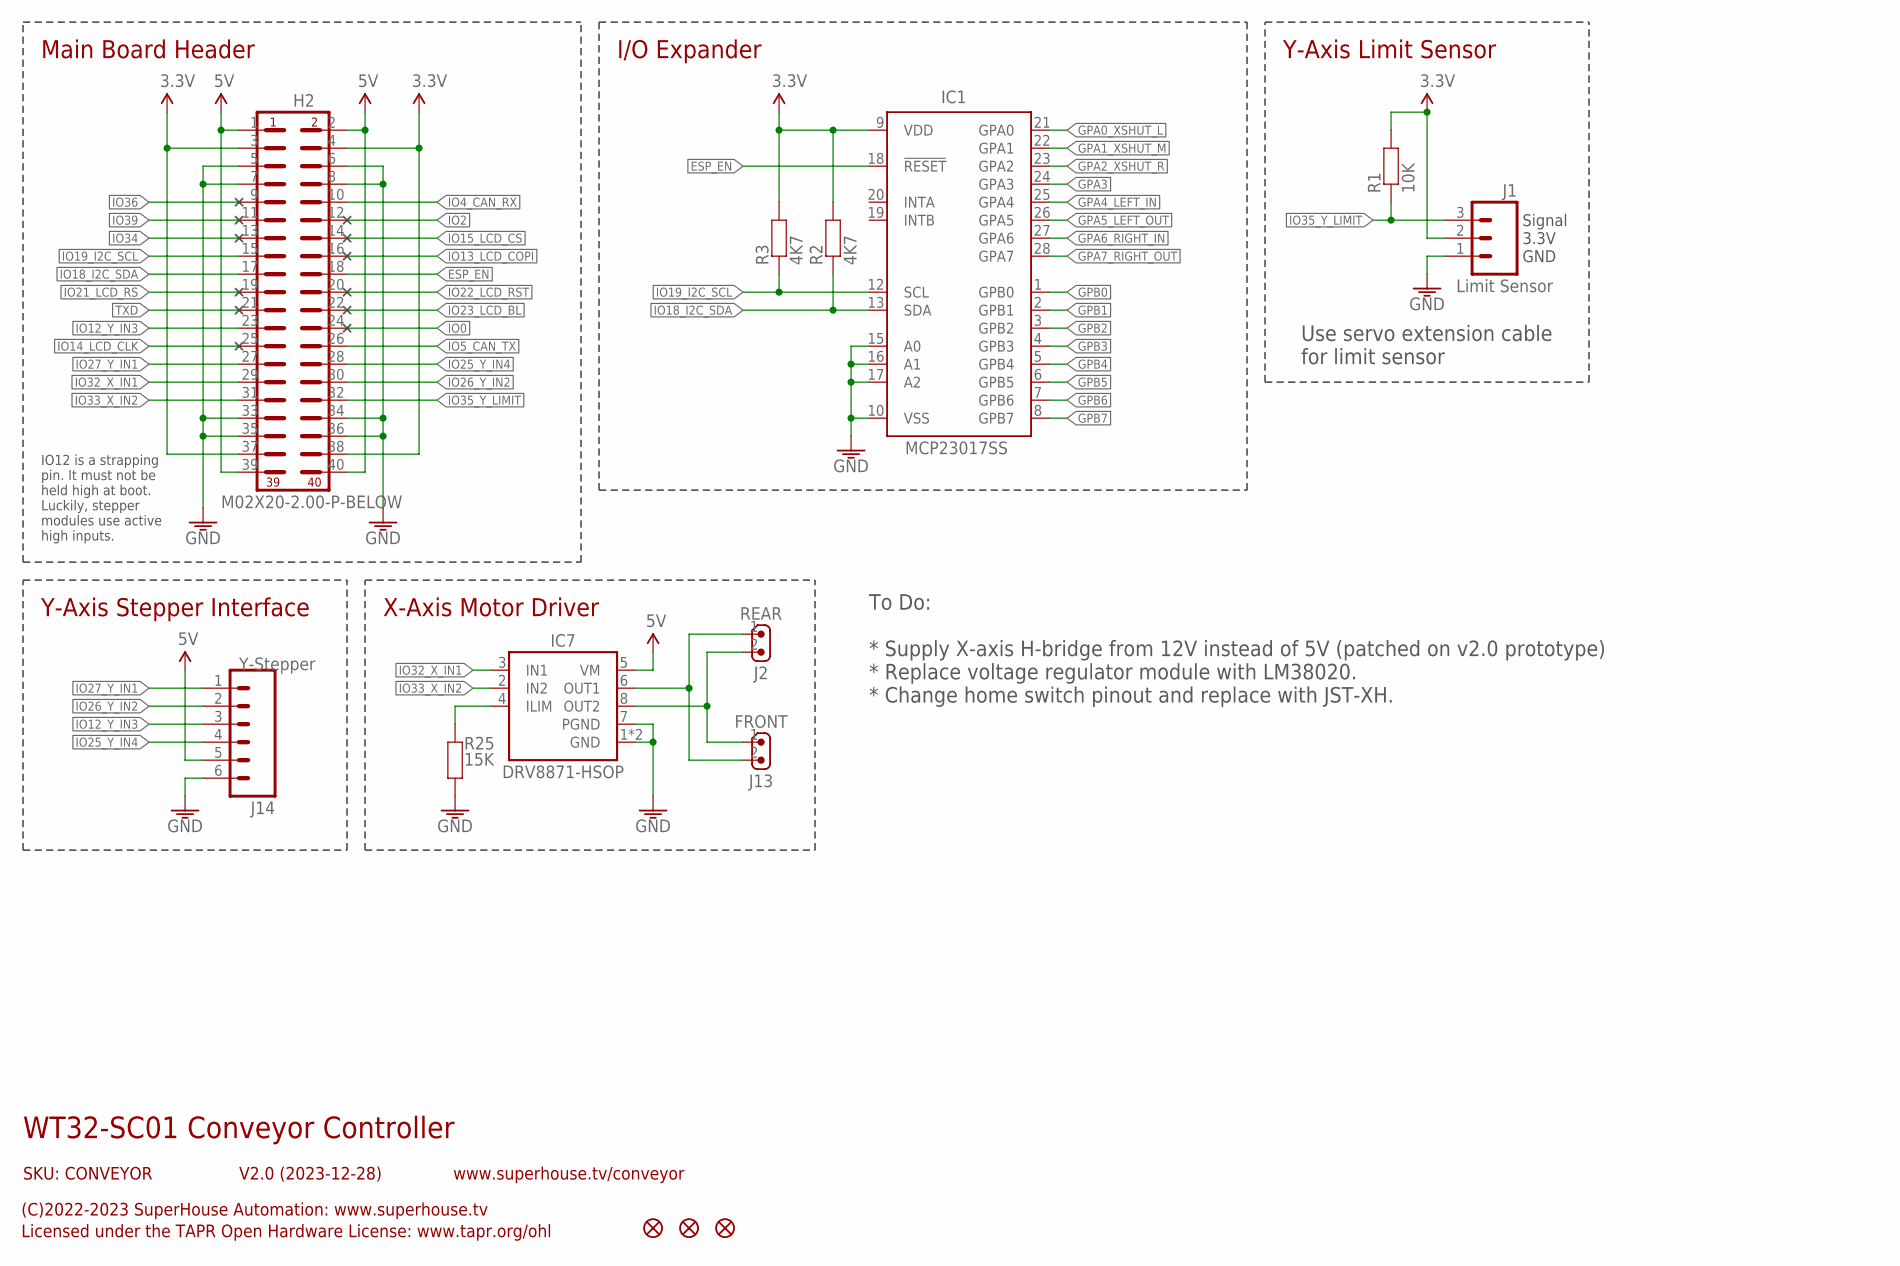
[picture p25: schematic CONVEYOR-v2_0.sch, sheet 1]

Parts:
H2: M02X20-2.00-P-BELOW; 2X20-2.00-P-BELOW
IC1: MCP23017SS; SSOP28
IC7: DRV8871-HSOP; SOIC8T
J1: Limit Sensor; 1X03-P
J2: REAR; JST-B2B-XH-A
J13: FRONT; JST-B2B-XH-A
J14: Y-Stepper; JST-B6B-XH-A
R1: 10K; R0603
R2, R3: 4K7; R0603
R25: 15K; R0603
U$4, U$5, U$6: FIDUCIAL1X2.5; FIDUCIAL-1X2.5

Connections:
3.3V: H2.3, H2.4, H2.37, H2.38, IC1.9 (VDD), J1.2, R1.2, R2.2, R3.2; also elsewhere on the board
5V: H2.1, H2.2, H2.39, H2.40, IC7.5 (VM), J14.5; also elsewhere on the board
ESP_EN: H2.18, IC1.18 (!RESET)
GND: H2.5, H2.6, H2.7, H2.8, H2.33, H2.34, H2.35, H2.36, IC1.10 (VSS), IC1.15 (A0), IC1.16 (A1), IC1.17 (A2), IC7.1 (GND), IC7.7 (PGND), IC7.TGND (GND), J1.1, J14.6, R25.1; also elsewhere on the board
GPA0_XSHUT_L: IC1.21 (GPA0); also elsewhere on the board
GPA1_XSHUT_M: IC1.22 (GPA1); also elsewhere on the board
GPA2_XSHUT_R: IC1.23 (GPA2); also elsewhere on the board
GPA3: IC1.24 (GPA3)
GPA4_LEFT_IN: IC1.25 (GPA4); also elsewhere on the board
GPA5_LEFT_OUT: IC1.26 (GPA5); also elsewhere on the board
GPA6_RIGHT_IN: IC1.27 (GPA6); also elsewhere on the board
GPA7_RIGHT_OUT: IC1.28 (GPA7); also elsewhere on the board
GPB0: IC1.1 (GPB0)
GPB1: IC1.2 (GPB1)
GPB2: IC1.3 (GPB2)
GPB3: IC1.4 (GPB3)
GPB4: IC1.5 (GPB4)
GPB5: IC1.6 (GPB5)
GPB6: IC1.7 (GPB6)
GPB7: IC1.8 (GPB7)
IO0: H2.24
IO2: H2.12
IO4_CAN_RX: H2.10; also elsewhere on the board
IO5_CAN_TX: H2.26; also elsewhere on the board
IO12_Y_IN3: H2.23, J14.3
IO13_LCD_COPI: H2.16
IO14_LCD_CLK: H2.25
IO15_LCD_CS: H2.14
IO18_I2C_SDA: H2.17, IC1.13 (SDA), R2.1; also elsewhere on the board
IO19_I2C_SCL: H2.15, IC1.12 (SCL), R3.1; also elsewhere on the board
IO21_LCD_RS: H2.19
IO22_LCD_RST: H2.20
IO23_LCD_BL: H2.22
IO25_Y_IN4: H2.28, J14.4
IO26_Y_IN2: H2.30, J14.2
IO27_Y_IN1: H2.27, J14.1
IO32_X_IN1: H2.29, IC7.3 (IN1)
IO33_X_IN2: H2.31, IC7.2 (IN2)
IO34: H2.13
IO35_Y_LIMIT: H2.32, J1.3, R1.1
IO36: H2.9
IO39: H2.11
unnamed: IC7.4 (ILIM), R25.2
unnamed: IC7.6 (OUT1), J2.1, J13.2
unnamed: IC7.8 (OUT2), J2.2, J13.1
TXD: H2.21

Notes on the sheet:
WT32-SC01 Conveyor Controller
SKU: CONVEYOR
(C)2022-2023 SuperHouse Automation: www.superhouse.tv
Licensed under the TAPR Open Hardware License: www.tapr.org/ohl
www.superhouse.tv/conveyor
V2.0 (2023-12-28)
Y-Axis Stepper Interface
Main Board Header
I/O Expander
3.3V
Signal
GND
Use servo extension cable for limit sensor
Y-Axis Limit Sensor
IO12 is a strapping pin. It must not be held high at boot. Luckily, stepper modules use active high inputs.
X-Axis Motor Driver
To Do: * Supply X-axis H-bridge from 12V instead of 5V (patched on v2.0 prototype) * Replace voltage regulator module with LM38020. * Change home switch pinout and replace with JST-XH.

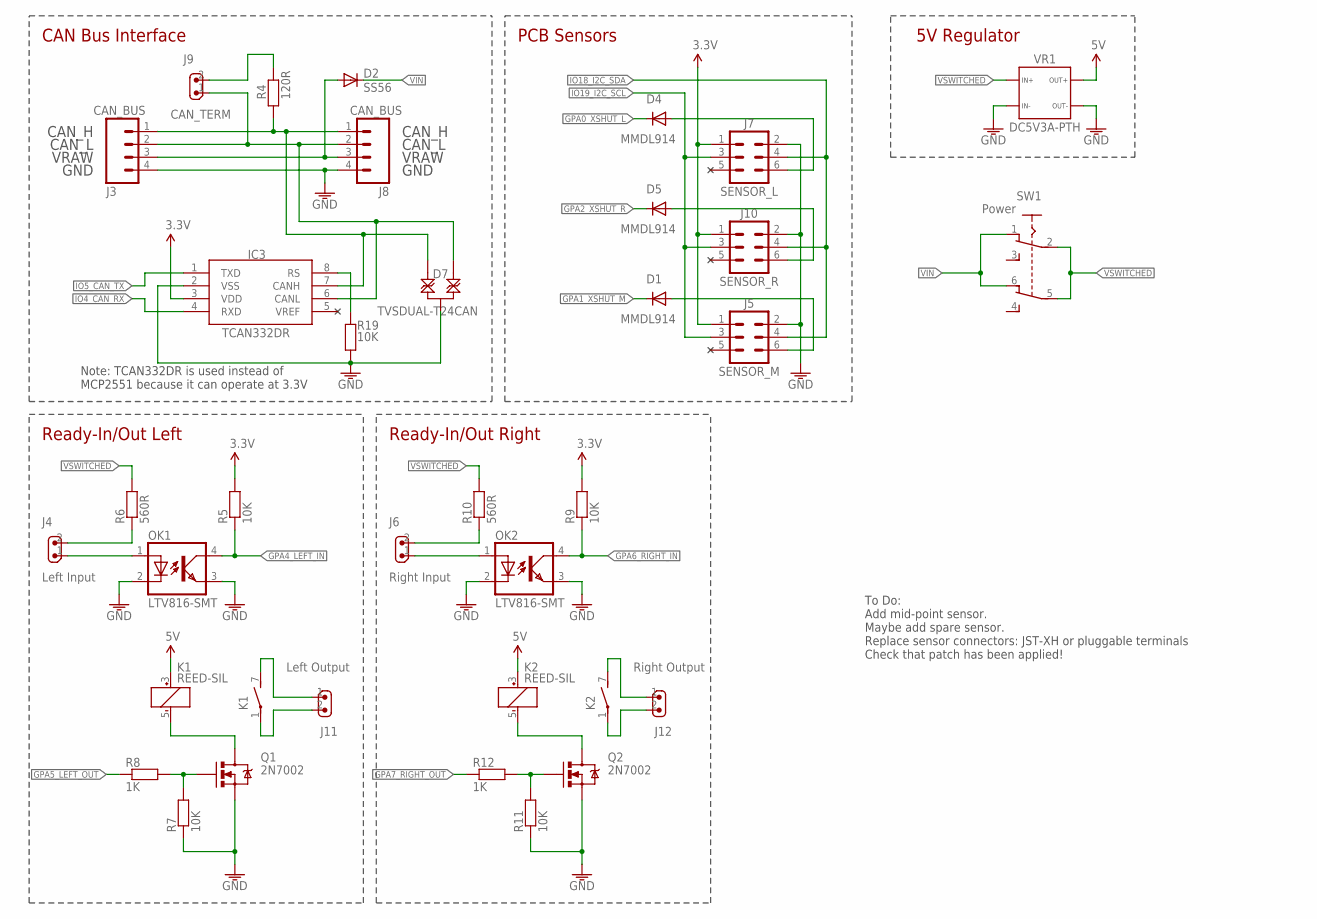
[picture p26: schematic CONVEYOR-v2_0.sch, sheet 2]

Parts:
D1, D4, D5: MMDL914; SOD-323
D2: SS56; SMA-DIODE
D7: TVSDUAL-T24CAN; SOT23-3
IC3: TCAN332DR; SO08
J3, J8: CAN_BUS; SCREWTERMINAL-3.81MM-VERT-4
J4: Left Input; 1X02-KF2510
J5: SENSOR_M; 2X3-2.54-SHROUDED
J6: Right Input; 1X02-KF2510
J7: SENSOR_L; 2X3-2.54-SHROUDED
J9: CAN_TERM; 1X02-P-JUMP-Y
J10: SENSOR_R; 2X3-2.54-SHROUDED
J11: Left Output; 1X02-KF2510
J12: Right Output; 1X02-KF2510
K1, K2: REED-SIL; REED
OK1, OK2: LTV816-SMT; SMD4
Q1, Q2: 2N7002; SOT23-3
R4: 120R; R2010
R5, R7, R9, R11, R19: 10K; R0603
R6, R10: 560R; R0603
R8, R12: 1K; R0603
SW1: Power; 7201SD9AV2BE
VR1: DC5V3A-PTH

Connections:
3.3V: IC3.3 (VDD), J5.1, J7.1, J10.1, R5.2, R9.2; also elsewhere on the board
5V: K1.3 (+), K2.3 (+), VR1.3A (3), VR1.3B (3); also elsewhere on the board
CAN_H1: D7.2, IC3.7 (CANH), J3.1, J8.1, R4.1
CAN_L1: D7.1, IC3.6 (CANL), J3.2, J8.2, J9.1
CAN_VIN: D2.A, J3.3, J8.3
GND: D7.3, IC3.2 (VSS), J3.4, J5.2, J7.2, J8.4, J10.2, OK1.2 (C), OK1.3 (EMIT), OK2.2 (C), OK2.3 (EMIT), Q1.2 (S), Q2.2 (S), R7.1, R11.1, R19.1, VR1.1A (1), VR1.1B (1), VR1.4A (4), VR1.4B (4); also elsewhere on the board
GPA0_XSHUT_L: D4.1 (C); also elsewhere on the board
GPA1_XSHUT_M: D1.1 (C); also elsewhere on the board
GPA2_XSHUT_R: D5.1 (C); also elsewhere on the board
GPA4_LEFT_IN: OK1.4 (COL), R5.1; also elsewhere on the board
GPA5_LEFT_OUT: R8.1; also elsewhere on the board
GPA6_RIGHT_IN: OK2.4 (COL), R9.1; also elsewhere on the board
GPA7_RIGHT_OUT: R12.1; also elsewhere on the board
IO4_CAN_RX: IC3.4 (RXD); also elsewhere on the board
IO5_CAN_TX: IC3.1 (TXD); also elsewhere on the board
IO18_I2C_SDA: J5.4, J7.4, J10.4; also elsewhere on the board
IO19_I2C_SCL: J5.3, J7.3, J10.3; also elsewhere on the board
unnamed: IC3.8 (RS), R19.2
unnamed: D1.2 (A), J5.6
unnamed: J9.2, R4.2
unnamed: D5.2 (A), J10.6
unnamed: J4.1, OK1.1 (A)
unnamed: J4.2, R6.1
unnamed: D4.2 (A), J7.6
unnamed: K1.5 (-), Q1.3 (D)
unnamed: J11.2, K1.1
unnamed: Q1.1 (G), R7.2, R8.2
unnamed: J11.1, K1.7 (S)
unnamed: Q2.1 (G), R11.2, R12.2
unnamed: K2.5 (-), Q2.3 (D)
unnamed: J12.2, K2.1
unnamed: J12.1, K2.7 (S)
unnamed: J6.1, OK2.1 (A)
unnamed: J6.2, R10.1
VIN: D2.C, SW1.1, SW1.6
VSWITCHED: R6.2, R10.2, SW1.2, SW1.5, VR1.2A (2), VR1.2B (2)

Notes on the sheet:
5V Regulator
CAN Bus Interface
Note: TCAN332DR is used instead of MCP2551 because it can operate at 3.3V
CAN_H
CAN_L
GND
VRAW
PCB Sensors
Ready-In/Out Left
Ready-In/Out Right
To Do: Add mid-point sensor. Maybe add spare sensor. Replace sensor connectors: JST-XH or pluggable terminals Check that patch has been applied!

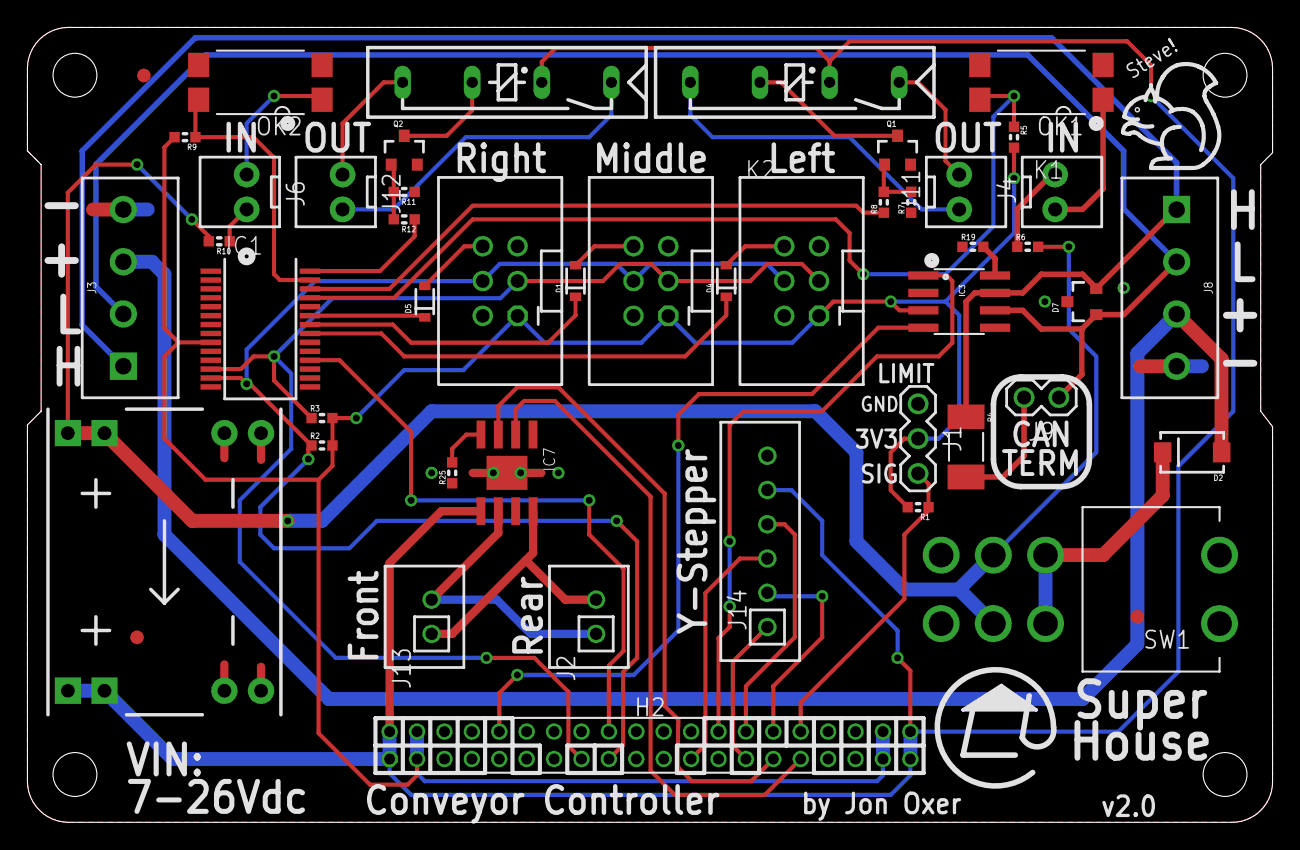
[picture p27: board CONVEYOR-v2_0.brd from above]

Board: 2 copper layers, 90.9 x 58.0 mm, 48 parts (0 on the bottom side), 47 nets.

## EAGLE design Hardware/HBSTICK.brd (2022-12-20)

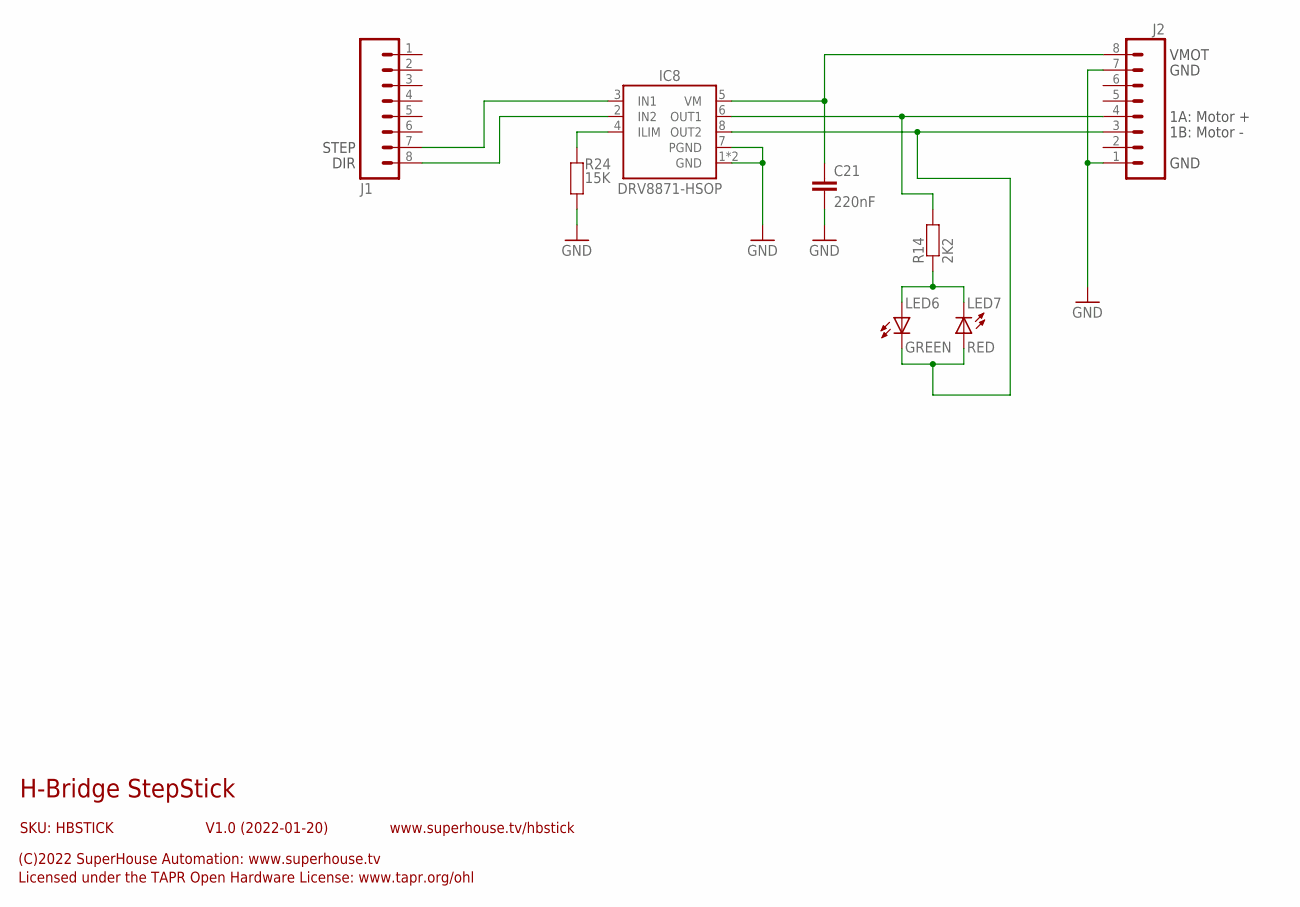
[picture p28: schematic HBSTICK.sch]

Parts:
C21: 220nF; C0603
IC8: DRV8871-HSOP; SOIC8T
J1, J2: M08-PIN-BELOW; 1X08-P-BELOW
LED6: GREEN; LED-0603
LED7: RED; LED-0603
R14: 2K2; R0603
R24: 15K; R0603

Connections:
GND: C21.2, IC8.1 (GND), IC8.7 (PGND), IC8.TGND (GND), J2.1, J2.7, R24.1
MOTOR+: IC8.6 (OUT1), J2.4, R14.2
MOTOR-: IC8.8 (OUT2), J2.3, LED6.C, LED7.A
unnamed: IC8.2 (IN2), J1.8
unnamed: IC8.3 (IN1), J1.7
unnamed: LED6.A, LED7.C, R14.1
unnamed: IC8.4 (ILIM), R24.2
VIN+: C21.1, IC8.5 (VM), J2.8

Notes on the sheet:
H-Bridge StepStick
SKU: HBSTICK
(C)2022 SuperHouse Automation: www.superhouse.tv
Licensed under the TAPR Open Hardware License: www.tapr.org/ohl
www.superhouse.tv/hbstick
V1.0 (2022-01-20)
VMOT
GND
1A: Motor +
1B: Motor -
STEP
DIR

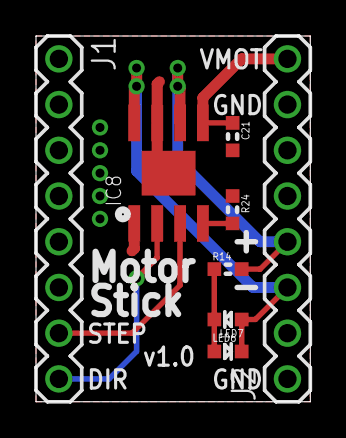
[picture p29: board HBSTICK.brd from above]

Board: 2 copper layers, 15.2 x 20.3 mm, 8 parts (0 on the bottom side), 8 nets.

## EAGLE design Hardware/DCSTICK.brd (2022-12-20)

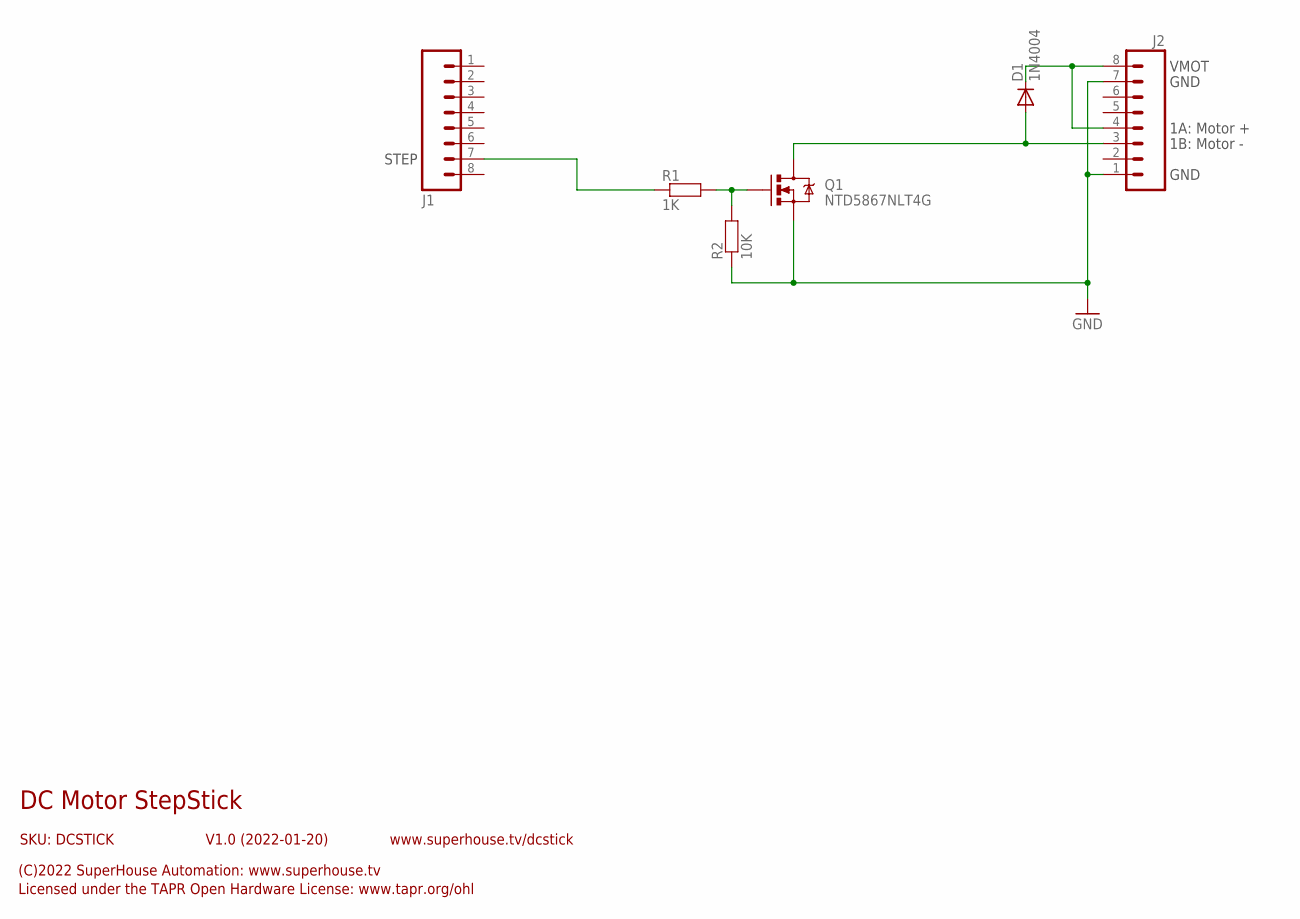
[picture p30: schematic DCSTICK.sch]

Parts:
D1: 1N4004; SMA-DIODE
J1, J2: M08-PIN-BELOW; 1X08-P-BELOW
Q1: NTD5867NLT4G; DPACK
R1: 1K; R0603
R2: 10K; R0603

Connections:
GND: J2.1, J2.7, Q1.3 (S), R2.1
unnamed: J1.7, R1.1
unnamed: Q1.1 (G), R1.2, R2.2
unnamed: D1.C, J2.4, J2.8
unnamed: D1.A, J2.3, Q1.2 (D)

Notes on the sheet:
DC Motor StepStick
SKU: DCSTICK
(C)2022 SuperHouse Automation: www.superhouse.tv
Licensed under the TAPR Open Hardware License: www.tapr.org/ohl
www.superhouse.tv/dcstick
V1.0 (2022-01-20)
VMOT
GND
1A: Motor +
1B: Motor -
STEP

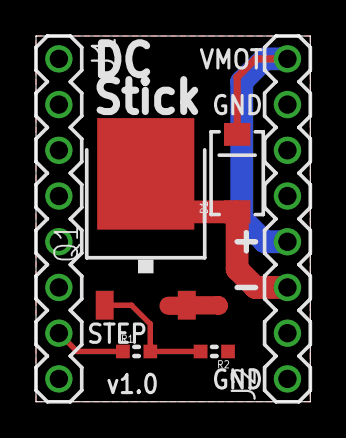
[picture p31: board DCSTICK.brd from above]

Board: 2 copper layers, 15.2 x 20.3 mm, 6 parts (0 on the bottom side), 5 nets.

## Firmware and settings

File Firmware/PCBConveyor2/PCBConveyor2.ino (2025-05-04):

/*
  PCB Conveyor Belt Firmware

  Written by Jonathan Oxer <jon@oxer.com.au>

  Controlled using GCODE. Understands these codes:

  "G28" does a Y-axis homing sequence. Arguments are ignored.
  "G0 Y<distance>" move the Y axis to the defined mm width.

  "M03 S<speed>"           Set the direction as clockwise (left to right) (default).
  "M04 S<speed>"           Set the direction as counterclockwise (right to left).
  "M05 S<speed>"           Stop the conveyor.

  "M10"                    Clamp a PCB                                      **DEFINED BUT NOT USED**
  "M11"                    Unclamp a PCB                                    **DEFINED BUT NOT USED**
  "M17 S<position>"        Request status of a sensor at <position>         **NOT YET IMPLEMENTED**

  "M50 S<speed>"           Load to middle immediately                       **NOT YET IMPLEMENTED**
  "M51 S<speed>"           Load to middle when ready-in/out                 **NOT YET IMPLEMENTED**
  "M52 S<speed>"           Load to end immediately                          **NOT YET IMPLEMENTED**
  "M53 S<speed>"           Load to end when ready-in/out                    **NOT YET IMPLEMENTED**
  "M54 S<speed>"           Move first board on the conveyor to the end      **NOT YET IMPLEMENTED**
  "M55 S<speed>"           Unload immediately
  "M56 S<speed>"           Unload when ready-in/out
  "M57 S<speed> P<dwell>"  Unload at a timed interval
  "M58 S<speed>"           Load and unload when ready-in/out                **NOT YET IMPLEMENTED**
  "M59 S<speed> P<dwell>"  Load when ready-in/out, unload at timed interval **NOT YET IMPLEMENTED**

  The <speed> argument is in mm/minute. Range is 600 - 2200mm/min.

  The <dwell> argument is in seconds.

  NOTE: There is no way to set the speed of the conveyor without giving
  left / right / stop as well. Perhaps add a config value for speed. Allan
  suggested a ramp up/down on speed change.
  ALSO: There is no way to set the direction without sending a move command.

  Arduino IDE ESP32 board profile:
  Go into Preferences -> Additional Board Manager URLs
  Add:
   https://dl.espressif.com/dl/package_esp32_index.json

  Then go to Tools -> Board -> Boards Manager..., update, and add "esp32 by Espressif Systems"

  Arduino IDE settings under "Tools":
    - Board:            ESP32 Dev Module
    - Upload speed:     115200bps
    - CPU Speed:        240MHz
    - Flash Frequency:  40MHz
    - Flash Mode:       DOUT
    - Flash Size:       4MB
    - Partition Scheme: Minimal SPIFFS (1.9MB APP with OTA/190KB SPIFFS)
    - Core Debug Level: None
    - PSRAM:            Disabled

  1. Make all the peripherals work
    To do:
    - Calibrate speed control of Y axis motor
    - Ready-in detection
    - Ready-out control
    Done:
    - PCB sensors
    - Homing sensor

  2. Direct control of operations
    To do:
    - Prevent Y-axis movement until the home sequence has been completed.
    Done:
    - Home
    - Set width
    - Move left / right / stop

  3. Objective-driven / mode operations
    - Unload PCB triggered by Ready-In from next machine (for feeding boards to PnP)
    - Load PCB to exit position
    - Load PCB to mid position
    Done:
    - Unload PCB triggered by M-Code command.
    - Timed unloading of PCBs (for feeding boards to reflow)

  BUGS:
    - MCU reboots periodically, for no reason I can see.
    - After rebooting, it won't respond to serial comms.

  TO DO:
    - PANIC stop!
    - Power to stepper through NC pins of limit switch at front position to prevent close collisions
    - Select pins for:
      - Read "s88 automation standard"
*/
#define VERSION "2.0"


/*--------------------------- Configuration ---------------------------------*/
// Configuration should be done in the included file:
#include "config.h"
#include "shhh_secret.h"

/*--------------------------- Libraries -------------------------------------*/
#include <Stepper.h>             // To drive the Y axis
#include <WiFi.h>                     // ESP32 WiFi driver
#include <PubSubClient.h>             // For MQTT
#include <ESPmDNS.h>                  // For OTA
#include <WiFiUdp.h>                  // For OTA
#include <ArduinoOTA.h>               // For OTA
#if ENABLE_LCD
#include <Arduino_GFX_Library.h>      // SPI LCD
#endif
#include <CAN.h>                      // By Sandeep Mistry
#include "Adafruit_VL53L0X.h"         // For ToF board sensors
#include <Adafruit_MCP23X17.h>        // For ToF sensors and in/out connections

/*--------------------------- Global Variables ------------------------------*/
#define  STOP   0
#define  LEFT   3
#define  RIGHT  4

#define  UNTRIPPED  0
#define  TRIPPED    1

#define  STATE_BEGIN       0
#define  STATE_IDLE        1
#define  STATE_ERROR       2
#define  STATE_STOPPED    10
#define  STATE_CONSTANT   11

// M55 S<speed>: Unload one board and then stop. This assumes a board is already sitting
// on the conveyor. Ignores ready-in/out.
#define  STATE_UNLOAD_NOW_BEGIN         550
#define  STATE_UNLOAD_NOW_MOVING        551
#define  STATE_UNLOAD_NOW_REACHED_END   552
#define  STATE_UNLOAD_NOW_CLEARED_END   553
#define  STATE_UNLOAD_NOW_RUNON         554   // Continue running briefly after PCB cleared sensor
// What state do we transition to after 23? 1? 10?

// M56 S<speed>: Unload when ready-in/out
#define  STATE_UNLOAD_RIRO_BEGIN        560
#define  STATE_UNLOAD_RIRO_MOVING       561
#define  STATE_UNLOAD_RIRO_REACHED_END  562
#define  STATE_UNLOAD_RIRO_CLEARED_END  563
#define  STATE_UNLOAD_RIRO_RUNON        564

// M57 S<speed> P<interval>: Unload boards at timed intervals. This assumes boards are
// already sitting on the conveyor. Ignores ready-in/out.
#define  STATE_UNLOAD_TIMED_BEGIN       570
#define  STATE_UNLOAD_TIMED_MOVING      571
#define  STATE_UNLOAD_TIMED_REACHED_END 572
#define  STATE_UNLOAD_TIMED_CLEARED_END 573
#define  STATE_UNLOAD_TIMED_PAUSE       574

#define  OUT_OF_RANGE           4     // TOF sensors return 4 when out of range

uint8_t  g_homed              = false;
uint16_t g_state              = STATE_BEGIN;
uint32_t g_last_state_change  = 0;    // timestamp of last state change
uint32_t step_count           = 0;
float    g_current_y_position = 0.0;

uint8_t  g_x_direction        = STOP; //
uint16_t g_x_requested_speed  = 0;    // mm/min
uint16_t g_x_actual_speed     = 0;    // mm/min
int16_t  g_requested_pause    = 0;    // Seconds. -1 indicates not set or invalid

#define  MAX_SERIAL_INPUT             50

// Wifi
#define  WIFI_CONNECT_INTERVAL       500   // Wait 500ms intervals for wifi connection
#define  WIFI_CONNECT_MAX_ATTEMPTS    10   // Number of attempts/intervals to wait

// MQTT
char g_mqtt_message_buffer[150];      // General purpose buffer for MQTT messages
char g_mqtt_command_topic[50];        // MQTT topic for receiving commands
char g_mqtt_tele_topic[50];           // MQTT topic for telemetry

// LCD
uint16_t g_lcd_width       = 0;
uint16_t g_lcd_height      = 0;
uint8_t  g_backlight_level = BACKLIGHT_LEVEL_HIGH;

// PCB sensors
VL53L0X_RangingMeasurementData_t g_pcb_sensor_l_reading;
VL53L0X_RangingMeasurementData_t g_pcb_sensor_m_reading;
VL53L0X_RangingMeasurementData_t g_pcb_sensor_r_reading;
bool     g_entrance_sensor = UNTRIPPED;
bool     g_middle_sensor   = UNTRIPPED;
bool     g_exit_sensor     = UNTRIPPED;
uint8_t  g_exit_sensor_count = 0;

// Ready-in / Ready-out handshaking
bool     g_ready_in_left   = false;
bool     g_ready_in_right  = false;


// General
char g_device_id[23];                 // Unique ID from ESP chip ID

// State machine variables
uint32_t g_runon_began      = 0;      // ms since runon began

/*--------------------------- Function Signatures ---------------------------*/
void initialise_pcb_sensors();
void debug_sensor_values();
void perform_state_transition(uint16_t g_state);

/*--------------------------- Macros ----------------------------------------*/

#if STATE_DEBUGGING
#define STATE_DEBUG_PRINT(x) Serial.print(x)
#define STATE_DEBUG_PRINTLN(x) Serial.println(x)
#else
#define STATE_DEBUG_PRINT(x)
#define STATE_DEBUG_PRINTLN(x)
#endif

/*--------------------------- Instantiate Global Objects --------------------*/
Stepper yAxisStepper(steps_per_revolution, PIN_Y_IN1, PIN_Y_IN3, PIN_Y_IN2, PIN_Y_IN4);
Adafruit_MCP23X17 mcp23017;
Adafruit_VL53L0X pcb_sensor_l = Adafruit_VL53L0X();
Adafruit_VL53L0X pcb_sensor_m = Adafruit_VL53L0X();
Adafruit_VL53L0X pcb_sensor_r = Adafruit_VL53L0X();

// MQTT
#if ENABLE_WIFI
WiFiClient esp_client;
PubSubClient client(esp_client);
#endif

#if ENABLE_LCD
Arduino_DataBus *bus = new Arduino_ESP32SPI(21 /* DC */, 15 /* CS */, 14 /* SCK */, 13 /* MOSI */, -1 /* MISO */);
Arduino_GFX *gfx = new Arduino_ST7796(bus, 22 /* RST */, 3 /* rotation */);
#endif

/*--------------------------- Program ---------------------------------------*/
/* Resources */
#include "motors.h"
#include "gcode.h"
#include "mqtt_comms.h"
#include "serial_comms.h"
#include "can_comms.h"
#include "pcb_sensors.h"
#include "riro.h"

/*
  Setup
*/
void setup()
{
  Serial.begin(SERIAL_BAUD_RATE);

  pinMode(LIMIT_SENSOR_Y_PIN,  INPUT );

  // #define CONV_MAX_SPEED  2200 // mm/minute
  // M03 S2200
  // 0 - 1023     500 - 800   300
  pinMode(PIN_X_IN1,           OUTPUT);
  pinMode(PIN_X_IN2,           OUTPUT);
  ledcSetup(0, MOTOR_PWM_FREQUENCY, 10); // Channel, frequency, resolution
  ledcSetup(1, MOTOR_PWM_FREQUENCY, 10); // Channel, frequency, resolution
  ledcAttachPin(PIN_X_IN1,          0);  // Pin, channel
  ledcAttachPin(PIN_X_IN2,          1);  // Pin, channel

  g_input_buffer.reserve(MAX_SERIAL_INPUT);
  yAxisStepper.setSpeed(13);  // RPM. Experiment with setting this higher.


#if ENABLE_LCD
  pinMode(TFT_BL_PIN,          OUTPUT);
  ledcSetup(2, MOTOR_PWM_FREQUENCY, 8);  // Channel, frequency, resolution
  ledcAttachPin(TFT_BL_PIN,         2);  // Pin, channel
  ledcWrite(2, g_backlight_level);

  // Initialize LCD
  gfx->begin();
  gfx->setRotation(1);
  g_lcd_width  = gfx->width();
  g_lcd_height = gfx->height();

  // Display banner
  gfx->setTextSize(3);
  gfx->fillScreen(BLACK);
  gfx->setTextColor(BLUE);
  gfx->setCursor(150, 8);
  gfx->println("SuperHouse");
  gfx->setTextColor(RED);
  gfx->print("    PCB Conveyor v");
  gfx->println(VERSION);
  gfx->println("");
#endif

  WiFi.mode(WIFI_STA);

  // We need a unique device ID for our MQTT client connection
  uint64_t chip_id = ESP.getEfuseMac(); // The chip ID is essentially its MAC address (length 6 bytes)
  uint16_t chip = (uint16_t)(chip_id >> 32);
  snprintf(g_device_id, 23, "%04x%08x", chip, (uint32_t)chip_id); // Use all the bytes
  Serial.print("Device ID: ");
  Serial.println(g_device_id);

  // Set up MQTT topics
  sprintf(g_mqtt_command_topic, "cmnd/%s/COMMAND",  g_device_id);  // For receiving commands
  sprintf(g_mqtt_tele_topic,    "tele/%s/TELE",     g_device_id);  // For telemetry

  // Report the MQTT topics to the serial console
  Serial.println("MQTT topics:");
  Serial.println(g_mqtt_command_topic);     // For receiving commands
  Serial.println(g_mqtt_tele_topic);        // For telemetry

#if ENABLE_LCD
  // Report the MQTT topics to the LCD
  gfx->setTextSize(2);
  //gfx->setCursor(0, 40);
  gfx->setTextColor(WHITE);
  gfx->print(" Commands:   ");
  gfx->setTextColor(GREEN);
  gfx->println(g_mqtt_command_topic);
  gfx->setTextColor(WHITE);
  gfx->print(" Telemetry:  ");
  gfx->setTextColor(GREEN);
  gfx->println(g_mqtt_tele_topic);
#endif

  // Set up the I/O expander for limit sensors and in/out connections
  Wire.begin(SDA_PIN, SCL_PIN);
  if (mcp23017.begin_I2C(MCP23017_ADDR)) {
    Serial.println("MCP23017 initialised ok");
    mcp23017.pinMode(PCB_SENSOR_L_XSHUT, OUTPUT);
    mcp23017.pinMode(PCB_SENSOR_M_XSHUT, OUTPUT);
    mcp23017.pinMode(PCB_SENSOR_R_XSHUT, OUTPUT);
    mcp23017.digitalWrite(PCB_SENSOR_L_XSHUT, LOW);
    mcp23017.digitalWrite(PCB_SENSOR_M_XSHUT, LOW);
    mcp23017.digitalWrite(PCB_SENSOR_R_XSHUT, LOW);
  } else {
    Serial.println("MCP23017 failed to initialise");
  }

  // Set up PCB sensors
  initialise_pcb_sensors();

  // Connect to WiFi
  if (initWifi()) {
    Serial.println("Wifi [CONNECTED]");
    Serial.println(WiFi.localIP());
    while (WiFi.waitForConnectResult() != WL_CONNECTED) {
      Serial.println("Connection Failed! Rebooting...");
      delay(1000);
      ESP.restart();
    }
    // Port defaults to 3232
    // ArduinoOTA.setPort(3232);

    // Hostname defaults to esp3232-[MAC]
    // ArduinoOTA.setHostname("myesp32");

    // No authentication by default
    // ArduinoOTA.setPassword("admin");

    // Password can be set with it's md5 value as well
    // MD5(admin) = 21232f297a57a5a743894a0e4a801fc3
    // ArduinoOTA.setPasswordHash("21232f297a57a5a743894a0e4a801fc3");
    ArduinoOTA.onStart([]()
    {
      String type;
      if (ArduinoOTA.getCommand() == U_FLASH)
        type = "sketch";
      else // U_SPIFFS
        type = "filesystem";

      // NOTE: if updating SPIFFS this would be the place to unmount SPIFFS using SPIFFS.end()
      Serial.println("Start updating " + type);
    })
    .onEnd([]() {
      Serial.println("\nEnd");
    })
    .onProgress([](unsigned int progress, unsigned int total) {
      Serial.printf("Progress: %u%%\r", (progress / (total / 100)));
    })
    .onError([](ota_error_t error) {
      Serial.printf("Error[%u]: ", error);
      if (error == OTA_AUTH_ERROR) Serial.println("Auth Failed");
      else if (error == OTA_BEGIN_ERROR) Serial.println("Begin Failed");
      else if (error == OTA_CONNECT_ERROR) Serial.println("Connect Failed");
      else if (error == OTA_RECEIVE_ERROR) Serial.println("Receive Failed");
      else if (error == OTA_END_ERROR) Serial.println("End Failed");
    });

    ArduinoOTA.begin();
#if ENABLE_LCD
    gfx->setTextColor(WHITE);
    gfx->print(" IP Address: ");
    gfx->setTextColor(GREEN);
    gfx->println(WiFi.localIP());
#endif
  } else {
    Serial.println("Wifi [FAILED]");
#if ENABLE_LCD
    gfx->setTextColor(WHITE);
    gfx->print(" IP Address: ");
    gfx->setTextColor(RED);
    gfx->println("FAILED");
#endif
  }

  /* Set up the MQTT client */
  client.setServer(mqtt_broker, 1883);
  client.setCallback(callback);

  /* Set up the CAN interface */
  if (ESP.getChipRevision() >= 2)
  {
    if (!CAN.begin(CAN_BUS_SPEED * 2))
    {
      Serial.println("CAN failed!");
    } else {
      Serial.print("CAN 2 initialised at ");
      Serial.println(CAN_BUS_SPEED);
    }
  } else {
    if (!CAN.begin(250E3))
    {
      Serial.println("CAN failed!");
    } else {
      Serial.print("CAN initialised at ");
      Serial.println(250E3);
    }
  }
}

/*
   Main loop
*/
void loop()
{
#if ENABLE_WIFI
  if (WiFi.status() == WL_CONNECTED)
  {
    if (!client.connected()) {
      reconnectMqtt();
    }
  }
  client.loop();  // Process any outstanding MQTT messages
  ArduinoOTA.handle();
#endif
  listenToSerialStream();
  //readCANMessages();
  setConveyorMotorSpeed();
  read_pcb_sensors();
  //debug_sensor_values();
  process_state_machine();
  check_ready_in();
}

void process_state_machine()
{
  switch (g_state)
  {
    case STATE_BEGIN:  // 0
      g_x_direction = STOP;
      break;

    case STATE_IDLE:  // 1
      g_x_direction = STOP;
      break;

    case STATE_ERROR:
      Serial.println("ERROR STATE");
      g_x_direction = STOP;
      break;

    /* UNLOAD_NOW block */
    case STATE_UNLOAD_NOW_BEGIN:  //
      g_x_direction = RIGHT;
      setConveyorMotorSpeed();
      perform_state_transition(STATE_UNLOAD_NOW_MOVING);
      break;

    case STATE_UNLOAD_NOW_MOVING:  //
      // Check exit sensor
      if (TRIPPED == g_exit_sensor)
      {
        perform_state_transition(STATE_UNLOAD_NOW_REACHED_END);
      }
      if (millis() > g_last_state_change + (UNLOAD_TIMEOUT * 1000))
      {
        g_x_direction = STOP;
        perform_state_transition(STATE_IDLE);
      }
      break;

    case STATE_UNLOAD_NOW_REACHED_END:  //
      // Check exit sensor
      if (UNTRIPPED == g_exit_sensor)
      {
        g_exit_sensor_count++;
        if (g_exit_sensor_count > SENSOR_DEBOUNCE_COUNT)
        {
          g_exit_sensor_count = 0;
          perform_state_transition(STATE_UNLOAD_NOW_CLEARED_END);
        }
      } else {
        g_exit_sensor_count = 0;
      }
      break;

    case STATE_UNLOAD_NOW_CLEARED_END:  // 23
      // Begin the runon timer
      g_runon_began = millis();
      perform_state_transition(STATE_UNLOAD_NOW_RUNON);
      break;

    case STATE_UNLOAD_NOW_RUNON:  //
      // Check the runon timer
      if (millis() > g_runon_began + RUNON_TIME)
      {
        g_x_direction = STOP;
        perform_state_transition(STATE_IDLE);
      }
      break;


    /* UNLOAD_RIRO block */
    case STATE_UNLOAD_RIRO_BEGIN:  //
      //g_x_direction = STOP;
      if (g_ready_in_right)
      {
        perform_state_transition(STATE_UNLOAD_RIRO_MOVING);
      }
      break;

    case STATE_UNLOAD_RIRO_MOVING:  //
      g_x_direction = RIGHT;
      setConveyorMotorSpeed();
      // Check exit sensor
      if (TRIPPED == g_exit_sensor)
      {
        perform_state_transition(STATE_UNLOAD_RIRO_REACHED_END);
      }
      if (millis() > g_last_state_change + (UNLOAD_TIMEOUT * 1000))
      {
        g_x_direction = STOP;
        perform_state_transition(STATE_IDLE);
      }
      break;

    case STATE_UNLOAD_RIRO_REACHED_END:  //
      // Check exit sensor
      if (UNTRIPPED == g_exit_sensor)
      {
        g_exit_sensor_count++;
        if (g_exit_sensor_count > SENSOR_DEBOUNCE_COUNT)
        {
          g_exit_sensor_count = 0;
          perform_state_transition(STATE_UNLOAD_RIRO_CLEARED_END);
        }
      } else {
        g_exit_sensor_count = 0;
      }
      break;

    case STATE_UNLOAD_RIRO_CLEARED_END:  // 23
      // Begin the runon timer
      g_runon_began = millis();
      perform_state_transition(STATE_UNLOAD_RIRO_RUNON);
      break;

    case STATE_UNLOAD_RIRO_RUNON:  //
      // Check the runon timer
      if (millis() > g_runon_began + RUNON_TIME)
      {
        g_x_direction = STOP;
        perform_state_transition(STATE_UNLOAD_RIRO_BEGIN);
      }
      break;


    /* UNLOAD_TIMED block */
    case STATE_UNLOAD_TIMED_BEGIN:  //
      g_x_direction = RIGHT;
      setConveyorMotorSpeed();
      perform_state_transition(STATE_UNLOAD_TIMED_MOVING);
      break;

    case STATE_UNLOAD_TIMED_MOVING:  //
      // Check exit sensor
      if (TRIPPED == g_exit_sensor)
      {
        perform_state_transition(STATE_UNLOAD_TIMED_REACHED_END);
      }
      if (millis() > g_last_state_change + (UNLOAD_TIMEOUT * 1000))
      {
        g_x_direction = STOP;
        perform_state_transition(STATE_IDLE);
      }
      break;

    case STATE_UNLOAD_TIMED_REACHED_END:  //
      // Check exit sensor
      if (UNTRIPPED == g_exit_sensor)
      {
        g_exit_sensor_count++;
        if (g_exit_sensor_count > SENSOR_DEBOUNCE_COUNT)
        {
          g_exit_sensor_count = 0;
          perform_state_transition(STATE_UNLOAD_TIMED_CLEARED_END);
        }
      } else {
        g_exit_sensor_count = 0;
      }
      break;

    // Board has been unloaded, waiting for the next board to arrive at the exit
    case STATE_UNLOAD_TIMED_CLEARED_END:  //
      // Check exit sensor
      if (TRIPPED == g_exit_sensor)
      {
        g_exit_sensor_count++;
        if (g_exit_sensor_count > SENSOR_DEBOUNCE_COUNT)
        {
          g_exit_sensor_count = 0;
          perform_state_transition(STATE_UNLOAD_TIMED_PAUSE);
          Serial.println("Leaving");
        }
      } else {
        g_exit_sensor_count = 0;
      }
      if (millis() > g_last_state_change + (UNLOAD_TIMEOUT * 1000))
      {
        g_x_direction = STOP;
        perform_state_transition(STATE_IDLE);
      }
      break;

    case STATE_UNLOAD_TIMED_PAUSE:  //
      g_x_direction = STOP;
      // Check the pause timer
      if (millis() > g_last_state_change + (g_requested_pause * 1000))
      {
        Serial.println("Leaving 2");
        perform_state_transition(STATE_UNLOAD_TIMED_BEGIN);
      }
      break;

    /* Catchall */
    default:
      perform_state_transition(STATE_ERROR);
      break;
  }
}


void perform_state_transition(uint16_t new_state)
{
  STATE_DEBUG_PRINT  ("sm: [");
  STATE_DEBUG_PRINT  (g_state);
  STATE_DEBUG_PRINT  (" -> ");
  STATE_DEBUG_PRINT  (new_state);
  STATE_DEBUG_PRINT("] @ ");
  STATE_DEBUG_PRINT(millis());
  STATE_DEBUG_PRINT(", delta ");
  STATE_DEBUG_PRINTLN(millis() - g_last_state_change);

  g_state = new_state;
  g_last_state_change = millis();
}


/**
  Connect to Wifi. Returns false if it can't connect.
*/
bool initWifi() {
  // Clean up any old auto-connections
  if (WiFi.status() == WL_CONNECTED) {
    WiFi.disconnect();
  }
  WiFi.setAutoConnect(false);

  // RETURN: No SSID, so no wifi!
  if (sizeof(ssid) == 1) {
    return false;
  }

  // Connect to wifi
  WiFi.begin(ssid, password);

  // Wait for connection set amount of intervals
  int num_attempts = 0;
  while (WiFi.status() != WL_CONNECTED && num_attempts <= WIFI_CONNECT_MAX_ATTEMPTS)
  {
    delay(WIFI_CONNECT_INTERVAL);
    num_attempts++;
  }

  if (WiFi.status() != WL_CONNECTED) {
    return false;
  } else {
    return true;
  }
}

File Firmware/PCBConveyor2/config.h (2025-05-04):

/* ----------------- General config -------------------------------- */
#define  ENABLE_WIFI               true
#define  ENABLE_MQTT               true
#define  ENABLE_LCD               false

#define  LIMIT_BACKOFF              100  // Steps, make it mm later
#define  HOME_SWITCH_OFFSET         297  // mm from 0 width to the homed position
#define  MINIMUM_CONVEYOR_POSITION   45  // Never go smaller than this
#define  MAXIMUM_CONVEYOR_POSITION  300  // Never go bigger than this
#define  MINIMUM_SPEED              600  // Never go slower than this
#define  MAXIMUM_SPEED             2200  // Never go faster than this

#define  RUNON_TIME                   0  // ms. Runtime after unload sensor cleared.
#define  LOAD_TIMEOUT                30  // Seconds. Stop if nothing appears within this time.
#define  UNLOAD_TIMEOUT              30  // Seconds. Stop if nothing gets to the exit within this time.
// Note: UNLOAD_TIMEOUT may be the wrong way of thinking about this, because the speed
// of the conveyor can vary. It probably needs to know how long it is, and then know
// how fast it's running so it can work out how long it needs to run.

#define  BACKLIGHT_LEVEL_HIGH        70
#define  BACKLIGHT_LEVEL_LOW         20

#define  SERIAL_DEBUGGING         false
#define  CAN_DEBUGGING            false
#define  STATE_DEBUGGING           true

/* WiFi */
//const char* ssid                   = "YOUR SSID";     // Your WiFi SSID
//const char* password               = "YOUR PSK";     // Your WiFi password

/* MQTT */
//const char* mqtt_broker            = "192.168.1.185"; // IP address of your MQTT broker
//const char* mqtt_username          = "YOUR USER";
//const char* mqtt_password          = "YOUR PASS";
//const char* status_topic           = "events";        // MQTT topic to report startup

/* Serial */
#define  SERIAL_BAUD_RATE        115200  // Speed for USB serial console

/* ----------------- Hardware-specific config ---------------------- */
/* X axis drive motors */
#define  MOTOR_PWM_FREQUENCY   5000  // Base frequency for PWM
#define  PIN_X_IN1               32
#define  PIN_X_IN2               33
#define  MOTOR_PWM_AT_MIN       200
#define  MOTOR_PWM_AT_MAX      1023

/* Y axis stepper motor */
#define  PIN_Y_IN1               27 //12 //19
#define  PIN_Y_IN2               26 //18
#define  PIN_Y_IN3               12
#define  PIN_Y_IN4               25 //17
const int steps_per_revolution = 2048;  // change this to fit the number of steps per revolution
//const int steps_per_revolution = 1024;  // change this to fit the number of steps per revolution
const float steps_per_mm       = 39.47;

/* Y axis limit sensor */
#define  LIMIT_SENSOR_Y_PIN       35 //16  // 

/* LCD */
#define  TFT_BL_PIN               23

/* PCB sensors */
#define  PCB_TRIGGER_HEIGHT       45    // Anything detected lower than this means a PCB is present at the sensor
#define  SENSOR_DEBOUNCE_COUNT    10    // Consecutive untriggered reads for board to be considered absent
#define  PCB_SENSOR_L_ADDR      0x30
#define  PCB_SENSOR_M_ADDR      0x31
#define  PCB_SENSOR_R_ADDR      0x32
#define  GPA0 0                         // Port A of IO expander
#define  GPA1 1                         // Port A of IO expander
#define  GPA2 2                         // Port A of IO expander
#define  GPA3 3
#define  GPA4 4
#define  GPA5 5
#define  GPA6 6
#define  GPA7 7
#define  PCB_SENSOR_L_XSHUT     GPA0
#define  PCB_SENSOR_M_XSHUT     GPA1
#define  PCB_SENSOR_R_XSHUT     GPA2

/* CAN bus */
#define  CAN_BUS_SPEED           250E3
#define  J1939_UPSTREAM_ADDRESS   0xF0   // Range for PnP: 0x80-8F, 0xF0-F1 (0xF0-F1 are reserved)
#define  J1939_SOURCE_ADDRESS     0x90   // Range for conveyors: 0x90-9F
#define  J1939_DOWNSTREAM_ADDRESS 0x80   // Range for PnP: 0x80-8F, 0xF0-F1 (0xF0-F1 are reserved)


//#define  CAN_RX_PIN                4
//#define  CAN_TX_PIN                5

/* I2C */
#define  SDA_PIN                  18
#define  SCL_PIN                  19
#define  MCP23017_ADDR          0x20

/* Ready-in / ready-out connections */
#define  READY_IN_LEFT_PIN        GPA4
#define  READY_OUT_LEFT_PIN       GPA5
#define  READY_IN_RIGHT_PIN       GPA6
#define  READY_OUT_RIGHT_PIN      GPA7

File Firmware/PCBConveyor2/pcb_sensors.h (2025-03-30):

#ifndef H_PCB_SENSORS
#define H_PCB_SENSORS

void initialise_pcb_sensors()
{
  // At this point all the XSHUT pins should be pulled low from setup,
  // but for completeness we'll make sure:
  mcp23017.digitalWrite(PCB_SENSOR_L_XSHUT, LOW);
  mcp23017.digitalWrite(PCB_SENSOR_M_XSHUT, LOW);
  mcp23017.digitalWrite(PCB_SENSOR_R_XSHUT, LOW);
  delay(10);

  // Bring them all up:
  mcp23017.digitalWrite(PCB_SENSOR_L_XSHUT, HIGH);
  mcp23017.digitalWrite(PCB_SENSOR_M_XSHUT, HIGH);
  mcp23017.digitalWrite(PCB_SENSOR_R_XSHUT, HIGH);
  delay(10);

  // Disable all but L sensor:
  mcp23017.digitalWrite(PCB_SENSOR_M_XSHUT, LOW);
  mcp23017.digitalWrite(PCB_SENSOR_R_XSHUT, LOW);
  delay(10);

  // Initialise the L sensor:
  if (!pcb_sensor_l.begin(PCB_SENSOR_L_ADDR))
  {
    Serial.println("Failed to initialise left PCB sensor.");
  } else {
    Serial.println("Initialised left PCB sensor.");
  }

  // Bring up the M sensor:
  mcp23017.digitalWrite(PCB_SENSOR_M_XSHUT, HIGH);
  delay(10);
  if (!pcb_sensor_m.begin(PCB_SENSOR_M_ADDR))
  {
    Serial.println("Failed to initialise middle PCB sensor.");
  } else {
    Serial.println("Initialised middle PCB sensor.");
  }
  //
  // Bring up the R sensor:
  mcp23017.digitalWrite(PCB_SENSOR_R_XSHUT, HIGH);
  delay(10);
  if (!pcb_sensor_r.begin(PCB_SENSOR_R_ADDR))
  {
    Serial.println("Failed to initialise right PCB sensor.");
  } else {
    Serial.println("Initialised right PCB sensor.");
  }
}

void read_pcb_sensors()
{
  // TODO: Add hysteresis logic to OUT OF RANGE tests near line 72,
  // and remove it from the state machine

  // NOTE: We need to account for direction of travel, and map l/r
  // to entrance / exit positions
  //  uint8_t entrance_sensor = 1;
  //  uint8_t middle_sensor = 2;
  //  uint8_t exit_sensor   = 3;

  //  uint16_t l_sensor_reading = g_pcb_sensor_l_reading.RangeMilliMeter;
  //  uint16_t m_sensor_reading = g_pcb_sensor_m_reading.RangeMilliMeter;

  pcb_sensor_l.rangingTest(&g_pcb_sensor_l_reading, false);
  uint16_t l_sensor_reading = g_pcb_sensor_l_reading.RangeMilliMeter;
  pcb_sensor_m.rangingTest(&g_pcb_sensor_m_reading, false);
  uint16_t m_sensor_reading = g_pcb_sensor_m_reading.RangeMilliMeter;
  pcb_sensor_r.rangingTest(&g_pcb_sensor_r_reading, false);
  uint16_t r_sensor_reading = g_pcb_sensor_r_reading.RangeMilliMeter;

  if (OUT_OF_RANGE != l_sensor_reading && l_sensor_reading < PCB_TRIGGER_HEIGHT)
  {
    g_entrance_sensor = TRIPPED;
  } else {
    g_entrance_sensor = UNTRIPPED;
  }

  if (OUT_OF_RANGE != m_sensor_reading && m_sensor_reading < PCB_TRIGGER_HEIGHT)
  {
    g_middle_sensor = TRIPPED;
  } else {
    g_middle_sensor = UNTRIPPED;
  }

  if (OUT_OF_RANGE != r_sensor_reading && r_sensor_reading < PCB_TRIGGER_HEIGHT)
  {
    g_exit_sensor = TRIPPED;
  } else {
    g_exit_sensor = UNTRIPPED;
  }
}

void debug_sensor_values()
{
  pcb_sensor_l.rangingTest(&g_pcb_sensor_l_reading, false);
  if (g_pcb_sensor_l_reading.RangeStatus != 4)
  {
    Serial.print("1: ");
    Serial.println(g_pcb_sensor_l_reading.RangeMilliMeter);
  } else {
    //Serial.println("Ranging error");
  }
  pcb_sensor_m.rangingTest(&g_pcb_sensor_m_reading, false);
  if (g_pcb_sensor_m_reading.RangeStatus != 4)
  {
    Serial.print("               2: ");
    Serial.println(g_pcb_sensor_m_reading.RangeMilliMeter);
  } else {
    //Serial.println("Ranging error");
  }
  pcb_sensor_r.rangingTest(&g_pcb_sensor_r_reading, false);
  if (g_pcb_sensor_r_reading.RangeStatus != 4)
  {
    Serial.print("                                3: ");
    Serial.println(g_pcb_sensor_r_reading.RangeMilliMeter);
  } else {
    //Serial.println("Ranging error");
  }
  delay(50);
}

#endif H_PCB_SENSORS

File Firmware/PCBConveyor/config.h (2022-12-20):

/* ----------------- General config -------------------------------- */
#define  ENABLE_WIFI               true
#define  ENABLE_MQTT               true

#define  LIMIT_BACKOFF              100  // Steps, make it mm later
#define  HOME_SWITCH_OFFSET         296  // mm from 0 width to the homed position
#define  MINIMUM_CONVEYOR_POSITION   45  // Never go smaller than this
#define  MAXIMUM_CONVEYOR_POSITION  300  // Never go bigger than this
#define  MINIMUM_SPEED              600  // Never go slower than this
#define  MAXIMUM_SPEED             2200  // Never go faster than this

#define  BACKLIGHT_LEVEL_HIGH        70
#define  BACKLIGHT_LEVEL_LOW         20

/* WiFi */
const char* ssid                   = "";     // Your WiFi SSID
const char* password               = "";     // Your WiFi password

/* MQTT */
const char* mqtt_broker            = "192.168.1.111"; // IP address of your MQTT broker
const char* status_topic           = "events";        // MQTT topic to report startup

/* Serial */
#define  SERIAL_BAUD_RATE        115200  // Speed for USB serial console

/* ----------------- Hardware-specific config ---------------------- */
/* Y axis stepper motor */
#define  PIN_IN1                  27 //12 //19
#define  PIN_IN2                  26 //18
#define  PIN_IN3                   5
#define  PIN_IN4                  25 //17
#define  MOTOR_PWM_FREQUENCY    5000  // Base frequency for PWM

const int steps_per_revolution = 2048;  // change this to fit the number of steps per revolution
const float steps_per_mm       = 39.47;

/* LCD */
#define  TFT_BL_PIN               23

/* Y axis limit sensor */
#define  LIMIT_SENSOR_Y_PIN       35 //16  // 

/* Conveyor motor driver */
#define  DRIVER_Y_A_PIN           99  // 25
#define  DRIVER_Y_B_PIN           99  // 26

/* PCB sensors */
#define  PCB_SENSOR_LEFT_PIN      99
#define  PCB_SENSOR_MIDDLE_PIN    99
#define  PCB_SENSOR_RIGHT_PIN     99

/* Ready-in / ready-out connections */
#define  READY_IN_LEFT_PIN        99
#define  READY_OUT_LEFT_PIN       99
#define  READY_IN_RIGHT_PIN       99
#define  READY_OUT_RIGHT_PIN      99

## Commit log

2021-12-23 Initial project import
    [2-Way Right Angle v4.3mf, PCBCONVEYOR.brd, PCBCONVEYOR.sch]
2022-12-20 v1.0 release.
    [PCBCONVEYOR.brd, PCBCONVEYOR.sch]
2022-12-20 Added Stepstick format board with N-MOSFET for simple DC drive.
    [DCSTICK.brd, DCSTICK.sch]
2022-12-20 Added Stepstick format board with H-Bridge for bidirectional DC motor drive.
    [HBSTICK.brd, HBSTICK.sch]
2022-12-20 Added controller pinout spreadsheet.
    [Controller-Pinout.ods]
2022-12-20 Added 3D files for some mechanical parts.
    [16mm Idler v2.3mf, 5mm Nut Spacer v3.3mf, Belt Idler Conveyor v6.3mf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]
2025-03-30 Added 3D models for most printable parts.
    [16mm Idler.3mf, 2-Way Right Angle.3mf, 5mm Nut Spacer.3mf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]
2025-04-01 Changed timed-dispense mode to queue the next board at the end of the conveyor. Added time reporting to state change debugging.
2025-05-04 Added v2.0 schematic and board layout
    [CONVEYOR-v2_0.brd, CONVEYOR-v2_0.sch]
2025-05-04 Added support for ready-in/out using CAN bus.
2025-11-25 Added v3.0 controller hardware design files.
    [CONVEYOR-v3_0.brd, CONVEYOR-v3_0.sch]

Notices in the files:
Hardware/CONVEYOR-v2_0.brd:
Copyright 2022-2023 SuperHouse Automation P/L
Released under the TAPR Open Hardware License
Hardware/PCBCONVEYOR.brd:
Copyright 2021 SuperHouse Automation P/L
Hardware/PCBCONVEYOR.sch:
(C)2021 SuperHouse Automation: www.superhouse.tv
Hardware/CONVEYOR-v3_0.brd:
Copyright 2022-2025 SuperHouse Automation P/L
